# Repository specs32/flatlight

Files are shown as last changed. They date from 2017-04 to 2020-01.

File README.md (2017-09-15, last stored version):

# flatlight

__What is Flatlight?__

A (relatively) powerful light, that nicely fits into your pockets because it's flat like a phone ;)

This Project is intended for educational and private use. (Probably to show how not to do a few things^^)

I designed the "Flatlight" myself, searching for circuits online, creating the schematics and layout with KiCAD.
I  built a few prototypes from bare copper PCB to the finished device, including printing the transparencys, exposing, developing, etching, cleaning, filing, placing the components and toasting the board on my old camping gas stove.

And as you can see im not much of a programmer ...

I got a lot of positive feedback from everyone, so I thought its time to share ! :)

__Building the Flatlight__

You should find everything you need in the KiCAD Folder to get started Hardwarewise.

__Code for the Flatlight__

It started out as a C++ Project in Eclipse, but i found that pretty difficult to set up and handle, so i switched to arduino.
The Arduino Programm is for the Flatlight . 

<B>The Software is Licensed under the GNU Public License 3.0, please include that in your Code</B>

<B> The Hardware is Licensed under CC-BY-SA 4.0 please include this on your Silkscreen or Top/Bottom Copper Layer</B>

Both Licenses can be found in the docs folder

Thanks to everyone who supported me  !!!

HAVE FUN !!!

-Nico

PS: Thanks and credits to cpldcpu for the nice tiny library which i forked here to adapt it to sk6812 RGBW LEDs!

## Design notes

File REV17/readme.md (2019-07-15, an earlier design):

___REV17 changes___

LEDSIDE
- added LED Driver dio5661
- removed temp ntc
- routed pwm through 2 pin header (standoffs and screws only carry VCC and GND now)

ESIDE
- removed NTC network
- added cap ref -> GND
- routed pwm though 2 pin header
- added OLED (0.91" 128x32 ssd1306)
- added IMU  (LSM6D3)
- changed pixels to apa102-2020 chips
- fliped position of pixels and switches
- changed softlatch mosfet to dmc1030ubqf-7 (some tweaking required here for sure)
- changed µC to atmega328-p with qfn-32 footprint
- changed lithium charge management to dio5158

TODO
- create BOM
- correct pin orientation for 2 pin header (pwm signal) on ledside !!!!

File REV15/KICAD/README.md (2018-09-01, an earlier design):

/*

Flatlight Rev 15

    --- KiCad Files

*/

NOTE :

KiCAD is updated to Version 5.x

It should be possible to open the pcbnew files with a fresh KiCad install, 
just add the libs and footprints in the KiCad settings and youre good to go !

The Project Files are in the PROJECT folder ;)

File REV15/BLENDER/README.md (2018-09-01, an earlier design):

/*

    Flatlight Rev 15
    
    --- Blender Files

*/

NOTE: 

Frame and Buttons are not finalized to Dimension, that Stuff is just here to get the Idea ;)

I use Mattercontrol to setup the Printer and export GCode ...

https://github.com/MatterHackers/MatterControl

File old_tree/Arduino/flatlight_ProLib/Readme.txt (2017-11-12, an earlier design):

The Library can be zipped and imported in Arduino(has to be greater version than 1.0.0) or can be directly copied in the
\Documents\Arduino\libraries\ProLib
directory to update the library you have to delete the old one manually and copy the new files in said directory.

The Library is still WIP and with the given .ino you can controll the LED Matrix.
Press the Moon Button to turn it on/off. Double press it to change the pattern. Hold it for Battery status.

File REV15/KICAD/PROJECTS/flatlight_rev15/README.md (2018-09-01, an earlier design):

/*

Flatlight Rev 15

 --- KiCad - Files

*/

NOTE : 

The gerber_rev15 folder contains updated PCB_NEW designs for kicad 
that are _not_ applied to the single PCB versions in the eside / ledside folders.

TODO : 

- need to update files single PCB files

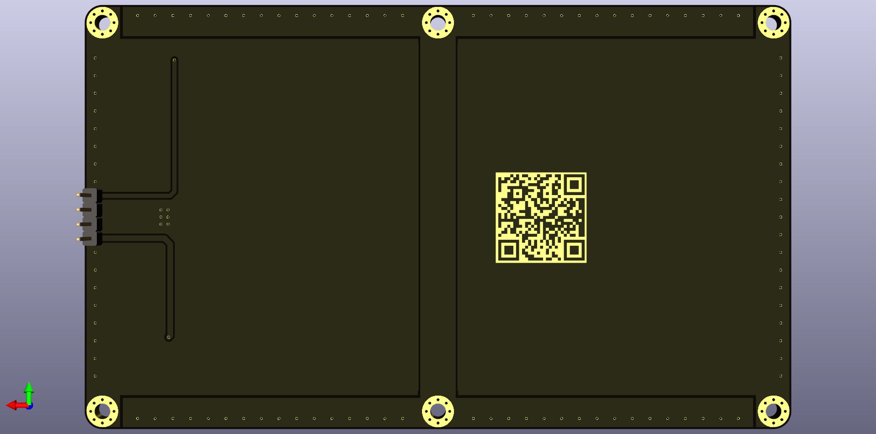
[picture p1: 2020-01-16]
REV18/KiCAD/Project/flatlight_rev18/ledside_rev18A/ledside_rev18A_back.png

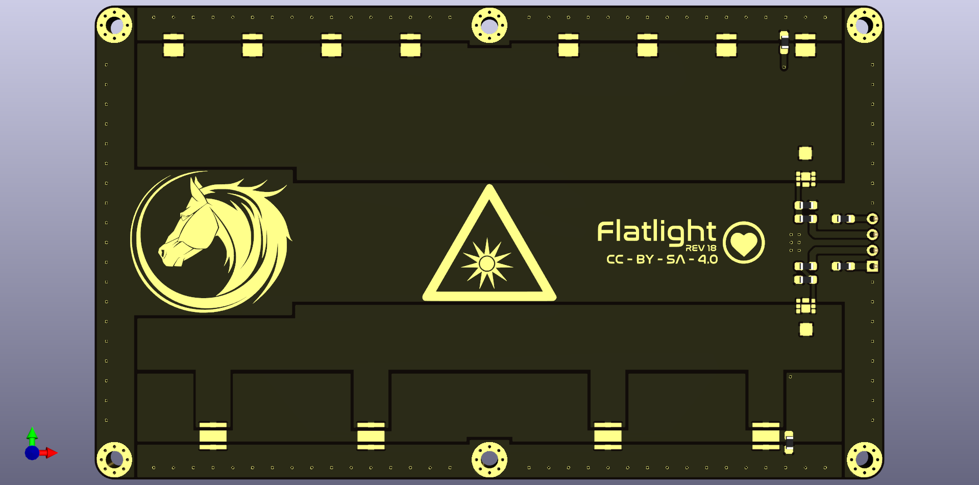
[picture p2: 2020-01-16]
REV18/KiCAD/Project/flatlight_rev18/ledside_rev18A/ledside_rev18A.png

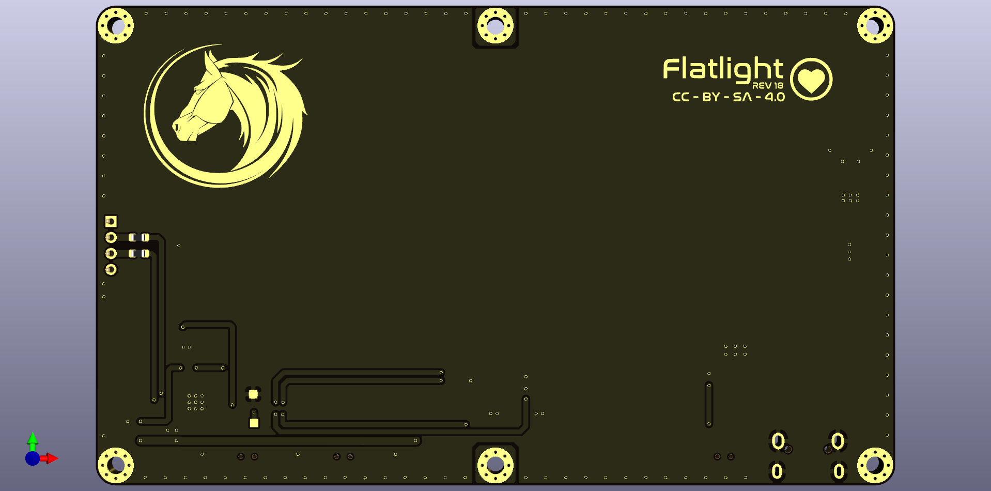
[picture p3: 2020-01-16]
REV18/KiCAD/Project/flatlight_rev18/eside_rev18A/eside_rev18.png

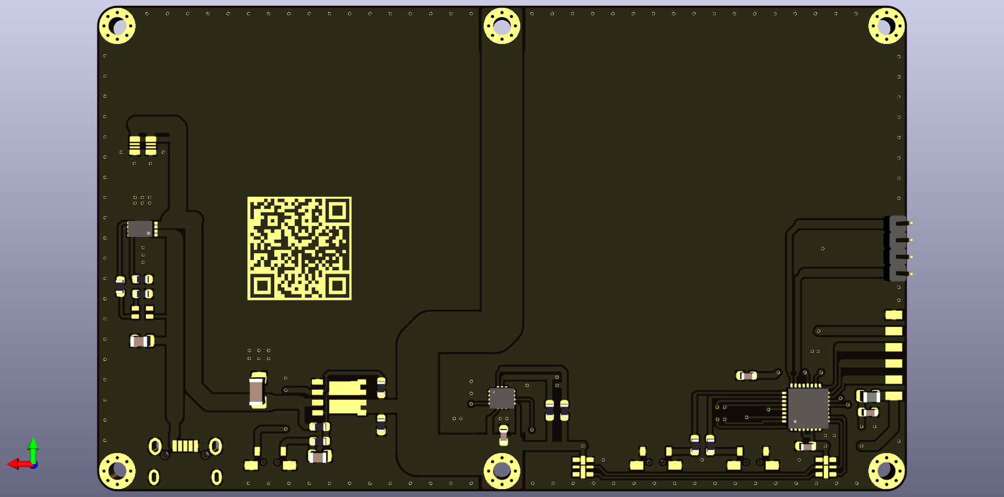
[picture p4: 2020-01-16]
REV18/KiCAD/Project/flatlight_rev18/eside_rev18A/eside_rev18_back.png

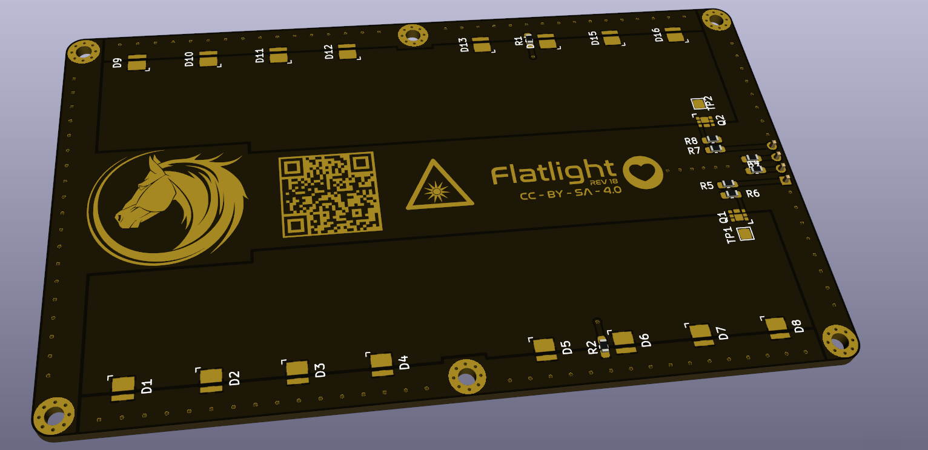
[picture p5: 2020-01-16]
REV18/Ledside_REV18A.png

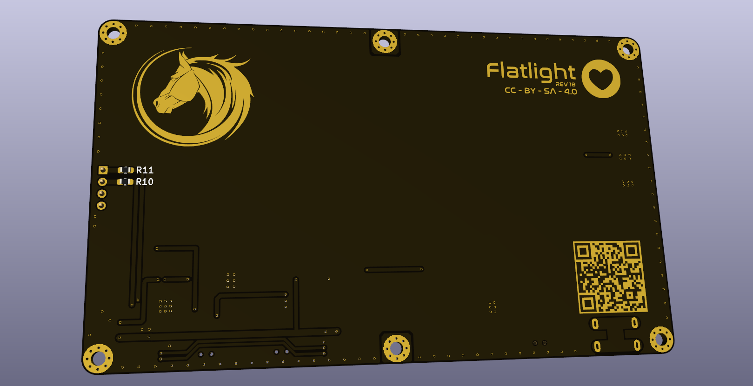
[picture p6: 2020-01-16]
REV18/ESide_REV18A.png

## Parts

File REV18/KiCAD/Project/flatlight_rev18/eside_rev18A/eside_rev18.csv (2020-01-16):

Id | Designator | Package | Quantity | Designation | Supplier and ref
1 | logo4 | logo_heart3 | 1 | logo-heart2
2 | logo1 | logo_flatlight | 1 | logo-flatlight
3 | R7,R6,R9,R8,R13,R12,R4 | R_0603_1608Metric | 7 | 1kΩ
4 | R10,R11,R3,R2 | R_0603_1608Metric | 4 | 10kΩ
5 | TP2,TP1 | TESTPOINT_0.6mm | 2 | TestPoint
6 | J1 | USB_Micro-B_Wuerth_629105150521 | 1 | USB_B_Micro
7 | L1 | L_0805_2012Metric | 1 | 10µH
8 | C5,C7,C4,C6 | C_0603_1608Metric | 4 | 100nF
9 | U2 | Bosch_LGA-14_3x2.5mm_P0.5mm | 1 | LSM6DS3
10 | J3 | PinHeader_1x04_P2.00mm_Vertical | 1 | Conn_01x04
11 | logo5 | logo_flatlight_git_silk | 1 | logo-flatlight-git
12 | logo3 | logo_horse | 1 | logo-horse
13 | logo6 | logo_REV18 | 1 | logo-rev18
14 | C2 | C_1206_3216Metric_Pad1.42x1.75mm_HandSolder | 1 | 10µF
15 | U3 | QFN-32-1EP_5x5mm_P0.5mm_EP3.1x3.1mm | 1 | ATmega328-MU
16 | D3,D2 | LED-APA102-2020 | 2 | APA102-2020
17 | SW3 | white_nano_smd_switch | 1 | BTN_DIG2
18 | SW2 | white_nano_smd_switch | 1 | BTN_DIG1
19 | SW1 | white_nano_smd_switch | 1 | BTN_PWR
20 | R5 | R_0603_1608Metric | 1 | 100kΩ
21 | R1 | R_0603_1608Metric | 1 | 2kΩ
22 | J2 | Conn_01x06_SMD_2mm | 1 | Conn_PROG
23 | H6,H5,H4,H3,H2,H1 | MountingHole_2.2mm_M2_Pad_Via | 6 | MountingHole_Pad
24 | C3 | C_0805_2012Metric | 1 | 1µF
25 | C1 | C_0805_2012Metric | 1 | 10µF
26 | logo2 | cc-by-sa | 1 | logo-cc-by-sa
27 | BT1 | lipo_samsung_BG930ABE | 1 | lipo_sams_BG930ABE
28 | D1 | 0606_ARGB_LED | 1 | LED_ARGB
29 | Q1 | PowerPAK_SO-8_Dual | 1 | DMC1016UPD
30 | U1 | DFN-8-1EP_3x2mm_P0.5mm_EP1.75x1.45mm | 1 | MCP73831-2x3DFN8

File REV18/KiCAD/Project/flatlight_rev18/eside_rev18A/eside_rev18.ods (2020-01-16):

Id | Designator | Package | Quantity | Designation | price per piece | row sum
1 | logo4 | logo_heart3 | 1 | logo-heart2 | 0.0000 EUR | 0.0000 €
2 | logo1 | logo_flatlight | 1 | logo-flatlight | 0.0000 EUR | 0.0000 €
3 | R7,R6,R9,R8,R13,R12,R4 | R_0603_1608Metric | 7 | 1kΩ | 0.0050 EUR | 0.0350 €
4 | R10,R11,R3,R2 | R_0603_1608Metric | 4 | 10kΩ | 0.0050 EUR | 0.0200 €
5 | TP2,TP1 | TESTPOINT_0.6mm | 2 | TestPoint | 0.0000 EUR | 0.0000 €
6 | J1 | USB_Micro-B_Wuerth_629105150521 | 1 | USB_B_Micro | 0.2000 EUR | 0.2000 €
7 | L1 | L_0805_2012Metric | 1 | 10µH | 0.1210 EUR | 0.1210 €
8 | C5,C7,C4,C6 | C_0603_1608Metric | 4 | 100nF | 0.0200 EUR | 0.0800 €
9 | U2 | Bosch_LGA-14_3x2.5mm_P0.5mm | 1 | LSM6DS3 | 2.6200 EUR | 2.6200 €
10 | J3 | PinHeader_1x04_P2.00mm_Vertical | 1 | Conn_01x04 | 0.1000 EUR | 0.1000 €
11 | logo5 | logo_flatlight_git_silk | 1 | logo-flatlight-git | 0.0000 EUR | 0.0000 €
12 | logo3 | logo_horse | 1 | logo-horse | 0.0000 EUR | 0.0000 €
13 | logo6 | logo_REV18 | 1 | logo-rev18 | 0.0000 EUR | 0.0000 €
14 | C2 | C_1206_3216Metric_Pad1.42x1.75mm_HandSolder | 1 | 10µF | 0.3300 EUR | 0.3300 €
15 | U3 | QFN-32-1EP_5x5mm_P0.5mm_EP3.1x3.1mm | 1 | ATmega328-MU | 2.3800 EUR | 2.3800 €
16 | D3,D2 | LED-APA102-2020 | 2 | APA102-2020 | 0.5000 EUR | 1.0000 €
17 | SW3 | white_nano_smd_switch | 1 | BTN_DIG2 | 0.1000 EUR | 0.1000 €
18 | SW2 | white_nano_smd_switch | 1 | BTN_DIG1 | 0.1000 EUR | 0.1000 €
19 | SW1 | white_nano_smd_switch | 1 | BTN_PWR | 0.1000 EUR | 0.1000 €
20 | R5 | R_0603_1608Metric | 1 | 100kΩ | 0.0050 EUR | 0.0050 €
21 | R1 | R_0603_1608Metric | 1 | 2kΩ | 0.0050 EUR | 0.0050 €
22 | J2 | Conn_01x06_SMD_2mm | 1 | Conn_PROG | 0.0000 EUR | 0.0000 €
23 | H6,H5,H4,H3,H2,H1 | MountingHole_2.2mm_M2_Pad_Via | 6 | MountingHole_Pad | 0.0000 EUR | 0.0000 €
24 | C3 | C_0805_2012Metric | 1 | 1µF | 0.0230 EUR | 0.0230 €
25 | C1 | C_0805_2012Metric | 1 | 10µF | 0.1170 EUR | 0.1170 €
26 | logo2 | cc-by-sa | 1 | logo-cc-by-sa | 0.0000 EUR | 0.0000 €
27 | BT1 | lipo_samsung_BG930ABE | 1 | lipo_sams_BG930ABE | 16.9900 EUR | 16.9900 €
28 | D1 | 0606_ARGB_LED | 1 | LED_ARGB | 0.1000 EUR | 0.1000 €
29 | Q1 | PowerPAK_SO-8_Dual | 1 | DMC1016UPD | 0.5580 EUR | 0.5580 €
30 | U1 | DFN-8-1EP_3x2mm_P0.5mm_EP1.75x1.45mm | 1 | MCP73831-2x3DFN8 | 0.5310 EUR | 0.5310 €
31 | D4,D3,D2,D1 | LED_Cree-XP-G | 4 | LED_PAD | 0.6160 EUR | 2.4640 €
32 | R3,R4 | R_0603_1608Metric_Pad1.05x0.95mm_HandSolder | 2 | NTC 10 kΩ | 0.1760 EUR | 0.3520 €
33 | R1,R2 | R_0603_1608Metric_Pad1.05x0.95mm_HandSolder | 2 | 10 kΩ | 0.0050 EUR | 0.0100 €
34 | logo7 | logo_flatlight_git_silk | 1 | logo_flatlight_git | 0.0000 EUR | 0.0000 €
35 | logo2 | logo_horse | 1 | logo_horse | 0.0000 EUR | 0.0000 €
36 | R6,R8 | R_0603_1608Metric_Pad1.05x0.95mm_HandSolder | 2 | 1MΩ | 0.0050 EUR | 0.0100 €
37 | TP1,TP2 | TestPoint_Pad_1.5x1.5mm | 2 | TestPoint | 0.0000 EUR | 0.0000 €
38 | R5,R7 | R_0603_1608Metric_Pad1.05x0.95mm_HandSolder | 2 | 1kΩ | 0.0050 EUR | 0.0100 €
39 | Q1,Q2 | U-DFN2020-6 (Type F) | 2 | DMN2022-UFDF7 | 0.2700 EUR | 0.5400 €
40 | D16,D15,D14,D13,D12,D11,D10,D9 | LED_Cree-J-Series | 8 | LED | 0.0820 EUR | 0.6560 €
41 | logo6 | logo_REV18 | 1 | logo_REV18 | 0.0000 EUR | 0.0000 €
42 | logo3 | cc-by-sa | 1 | logo-cc-by-sa | 0.0000 EUR | 0.0000 €
43 | J1 | PinHeader_1x04_P2.00mm_Vertical | 1 | Conn_01x04 | 0.1000 EUR | 0.1000 €
44 | H6,H5,H4,H3,H2,H1 | MountingHole_2.2mm_M2_Pad_Via | 6 | MountingHole_Pad | 0.0000 EUR | 0.0000 €
45 | logo1 | logo_heart3 | 1 | logo_heart | 0.0000 EUR | 0.0000 €
46 | logo5 | logo_flatlight | 1 | logo_flatlight | 0.0000 EUR | 0.0000 €
47 | logo4 | logo_lightwarn_15mm | 1 | logo_LIGHTWARN | 0.0000 EUR | 0.0000 €
48 | verbrauch | zinn, flux, draht, etc. | 1 |  | 3.0000 EUR | 3.0000 €
49 | messing einsätze | rahmen besfestigung | 6 |  | 0.0700 EUR | 0.4200 €
50 | schrauben | rahmen besfestigung | 6 |  | 0.0100 EUR | 0.0600 €
51 |  |  |  |  |  | 33.1370 €

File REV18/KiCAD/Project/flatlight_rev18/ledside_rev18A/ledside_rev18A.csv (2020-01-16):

Id | Designator | Package | Quantity | Designation | Supplier and ref
1 | D4,D3,D2,D1 | LED_Cree-XP-G | 4 | LED_PAD
2 | R3,R4 | R_0603_1608Metric_Pad1.05x0.95mm_HandSolder | 2 | NTC 10 kΩ
3 | R1,R2 | R_0603_1608Metric_Pad1.05x0.95mm_HandSolder | 2 | 10 kΩ
4 | logo7 | logo_flatlight_git_silk | 1 | logo_flatlight_git
5 | logo2 | logo_horse | 1 | logo_horse
6 | R6,R8 | R_0603_1608Metric_Pad1.05x0.95mm_HandSolder | 2 | 1MΩ
7 | TP1,TP2 | TestPoint_Pad_1.5x1.5mm | 2 | TestPoint
8 | R5,R7 | R_0603_1608Metric_Pad1.05x0.95mm_HandSolder | 2 | 1kΩ
9 | Q1,Q2 | U-DFN2020-6 (Type F) | 2 | DMN2022-UFDF7
10 | D16,D15,D14,D13,D12,D11,D10,D9 | LED_Cree-J-Series | 8 | LED
11 | logo6 | logo_REV18 | 1 | logo_REV18
12 | logo3 | cc-by-sa | 1 | logo-cc-by-sa
13 | J1 | PinHeader_1x04_P2.00mm_Vertical | 1 | Conn_01x04
14 | H6,H5,H4,H3,H2,H1 | MountingHole_2.2mm_M2_Pad_Via | 6 | MountingHole_Pad
15 | logo1 | logo_heart3 | 1 | logo_heart
16 | logo5 | logo_flatlight | 1 | logo_flatlight
17 | logo4 | logo_lightwarn_15mm | 1 | logo_LIGHTWARN

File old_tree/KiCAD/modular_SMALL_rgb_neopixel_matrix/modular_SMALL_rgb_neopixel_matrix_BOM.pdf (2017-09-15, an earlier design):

modular_SMALL_rgb_neopixel_matrix

Kicad Rev | Eeschema 4.0.6
Date Issue | Sat 09 Sep 2017 10:44:32 GMT
Title | Modular Flatlight
Company | Nicolas Rosenthal
Revision | 8
Date Issue | 2017-07-24
Comment | CC-BY-SA-4.0
Comment | Flatlight
Reference | Value | Library | Library Ref | Price
Q1 | IRF7319 | transistors | IRF7343PBF | 0.411760 €
U1 | TP4056 | nicos-parts | TP4056 | 0.360000 €
J1 | USB_Micro_Jack | conn | USB_B | 0.520000 €
R1 | 1.2KΩ | device | R | 0.005880 €
R2 | 1KΩ | device | R | 0.005880 €
R3 | 1KΩ | device | R | 0.058800 €
D1 | RED | device | LED | 0.067230 €
D2 | GREEN | device | LED | 0.084030 €
C1 | 10µF | device | C | 0.050420 €
C2 | 10µF | device | C | 0.050420 €
R6 | 100KΩ | device | R | 0.005880 €
R5 | 10KΩ | device | R | 0.005880 €
R4 | 100KΩ | device | R | 0.005880 €
C3 | 1µF | device | C | 0.033610 €
R7 | 10KΩ | device | R | 0.005880 €
SW1 | SW_PWR | switches | SW_Push | 0.040000 €
C7 | 100nF_decoupling | device | C | 0.033610 €
D9 | TMPWARN_RED | device | LED | 0.067230 €
R23 | 237Ω | device | R | 0.005880 €
SW2 | SW_MODE | switches | SW_Push | 0.040000 €
R22 | 10KΩ | device | R | 0.005880 €
D8 | PWRLED_GRN | device | LED | 0.180000 €
R21 | 237Ω | device | R | 0.005880 €
R17 | 15KΩ | device | R | 0.005880 €
BAT1 | LIPO_W_NTC | nicos-parts | LIPO_W_NTC | 3.850000 €
D7 | CHRG_IND_RED | device | LED | 0.067230 €
D6 | CHRG_IND_ORANGE | device | LED | 0.084030 €
D5 | CHRG_IND_YELLOW | device | LED | 0.050420 €
D4 | CHRG_IND_GREEN | device | LED | 0.084030 €
D3 | CHRG_IND_BRTGREEN | device | LED | 0.134450 €
RN1 | R_Pack_220Ω | device | R_Pack04 | 0.016800 €
R8 | 237Ω | device | R | 0.005880 €
J12 | CONN_VCC_FEMALE | conn | CONN_01X03 | 0.100000 €
J10 | CONN_PWM_1_FEMALE | conn | CONN_01X03 | 0.100000 €
J6 | CONN_VCC_FEMALE | conn | CONN_01X03 | 0.100000 €
J4 | CONN_PWM_2_FEMALE | conn | CONN_01X03 | 0.100000 €
U2 | ATMEGA16-16AU | atmel | ATMEGA16-16AU | 1.630000 €
C6 | 100nF | device | C | 0.033610 €

L1 | 100µH | device | L | 0.160000 €
SW3 | SW_MODE2 | switches | SW_Push | 0.040000 €
R9 | 10KΩ | device | R | 0.005880 €
J2 | CONN_01X08 | conn | CONN_01X08 | 0.200000 €
Q2 | IRLML6244 | device | Q_NMOS_GSD | 0.190240 €
R10 | 1KΩ | device | R | 0.005880 €
C4 | 10µF TANT | device | CP | 0.100800 €
U26 | SK6812 | SK6812_3535 LED | 0.100000 €
C27 | 100nF | device | C | 0.033610 €
U27 | SK6812 | SK6812_3535 LED | 0.100000 €
C28 | 100nF | device | C | 0.033610 €
U28 | SK6812 | SK6812_3535 LED | 0.100000 €
C29 | 100nF | device | C | 0.033610 €
U29 | SK6812 | SK6812_3535 LED | 0.100000 €
C30 | 100nF | device | C | 0.033610 €
U30 | SK6812 | SK6812_3535 LED | 0.100000 €
C31 | 100nF | device | C | 0.033610 €
U31 | SK6812 | SK6812_3535 LED | 0.100000 €
C32 | 100nF | device | C | 0.033610 €
U32 | SK6812 | SK6812_3535 LED | 0.100000 €
C33 | 100nF | device | C | 0.033610 €
U33 | SK6812 | SK6812_3535 LED | 0.100000 €
C34 | 100nF | device | C | 0.033610 €
U34 | SK6812 | SK6812_3535 LED | 0.100000 €
C35 | 100nF | device | C | 0.033610 €
U35 | SK6812 | SK6812_3535 LED | 0.100000 €
C36 | 100nF | device | C | 0.033610 €
U36 | SK6812 | SK6812_3535 LED | 0.100000 €
C37 | 100nF | device | C | 0.033610 €
U37 | SK6812 | SK6812_3535 LED | 0.100000 €
C38 | 100nF | device | C | 0.033610 €
U38 | SK6812 | SK6812_3535 LED | 0.100000 €
C39 | 100nF | device | C | 0.033610 €
U39 | SK6812 | SK6812_3535 LED | 0.100000 €
C40 | 100nF | device | C | 0.033610 €
U40 | SK6812 | SK6812_3535 LED | 0.100000 €
C41 | 100nF | device | C | 0.033610 €
U41 | SK6812 | SK6812_3535 LED | 0.100000 €
C42 | 100nF | device | C | 0.033610 €
U42 | SK6812 | SK6812_3535 LED | 0.100000 €
C43 | 100nF | device | C | 0.033610 €
U43 | SK6812 | SK6812_3535 LED | 0.100000 €
C44 | 100nF | device | C | 0.033610 €
U44 | SK6812 | SK6812_3535 LED | 0.100000 €
C45 | 100nF | device | C | 0.033610 €
U45 | SK6812 | SK6812_3535 LED | 0.100000 €
C46 | 100nF | device | C | 0.033610 €
U46 | SK6812 | SK6812_3535 LED | 0.100000 €
C47 | 100nF | device | C | 0.033610 €

U47 | SK6812 | SK6812_3535 LED | 0.100000 €
C48 | 100nF | device | C | 0.033610 €
U48 | SK6812 | SK6812_3535 LED | 0.100000 €
J4 | CONN_01X03 | conn | CONN_01X03 | 0.100000 €
J1 | CONN_01X03 | conn | CONN_01X03 | 0.100000 €
J2 | CONN_01X03 | conn | CONN_01X03 | 0.100000 €
J5 | CONN_01X03 | conn | CONN_01X03 | 0.100000 €
J3 | CONN_01X08 | conn | CONN_01X08 | 0.200000 €
MAT | Fotoplatine | | | 2.550000 €
MAT | Ätzmittel | | | 0.500000 €
MAT | Epoxy | | | 0.500000 €
MAT | VIAS | | | 0.500000 €
MAT | Folie,Draht,Klebeband,Zinn,etc | | | 1.000000 €
GESAMT | | | | 17.804580 €

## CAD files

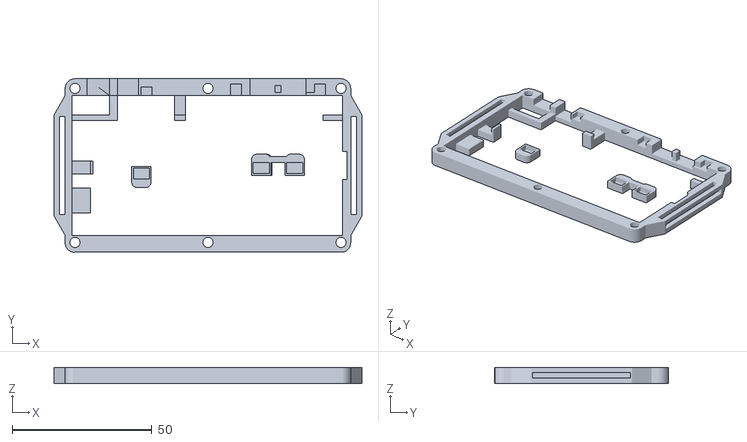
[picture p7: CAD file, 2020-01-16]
REV18/Blender/flatlight_rev18.stl
110.0 x 62.0 x 5.80

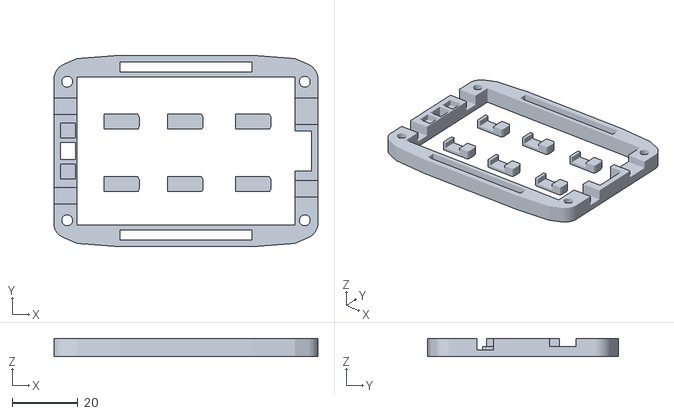
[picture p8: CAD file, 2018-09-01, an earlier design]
REV15/BLENDER/flatlight_rev15/flatlight_rev15_16.stl
80.0 x 58.0 x 5.50

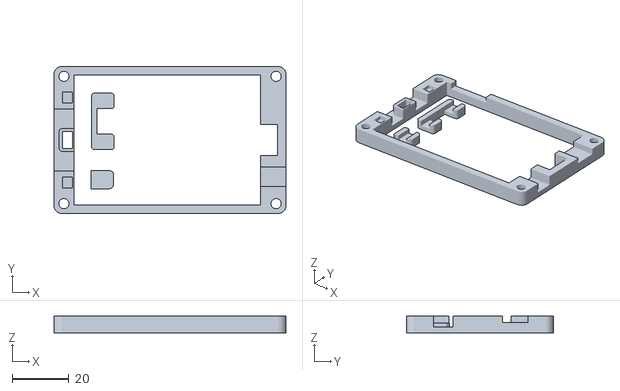
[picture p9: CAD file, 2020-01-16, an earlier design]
REV17/Blender/flatlight_rev17_28.stl
82.0 x 52.0 x 5.90

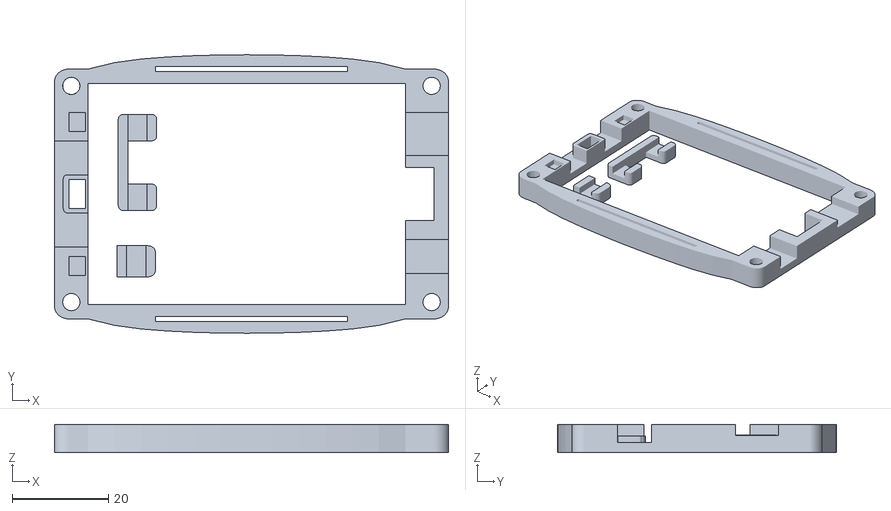
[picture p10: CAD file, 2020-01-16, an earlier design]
REV17/Blender/flatlight_rev17_30.stl
82.0 x 58.0 x 5.90

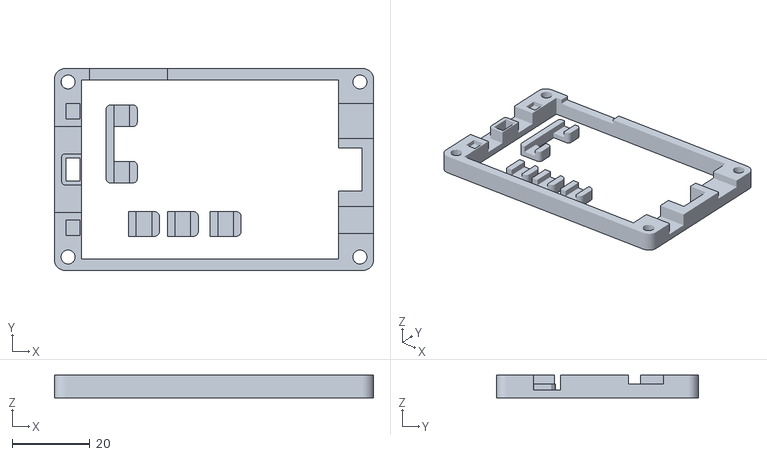
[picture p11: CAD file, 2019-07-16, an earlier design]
REV17/Blender/flatlight_rev17_22.stl
82.0 x 52.0 x 5.80

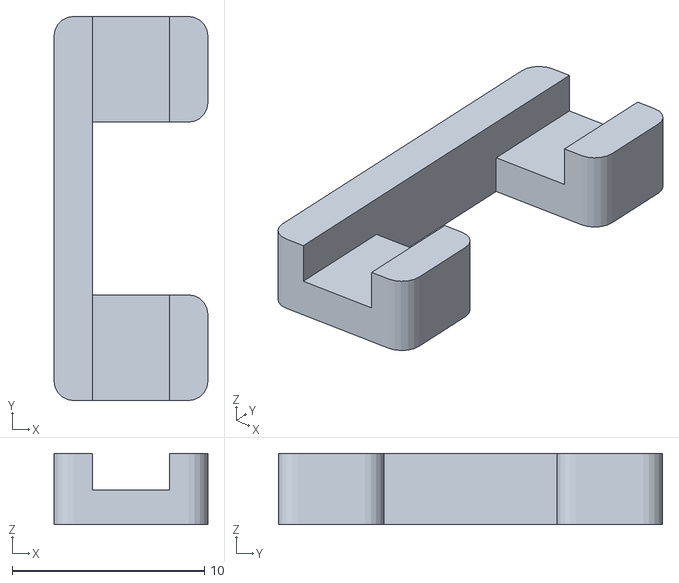
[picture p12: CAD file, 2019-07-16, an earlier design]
REV17/Blender/flatlight_rev17_23-Cube_001.stl
8.01 x 20.0 x 3.70

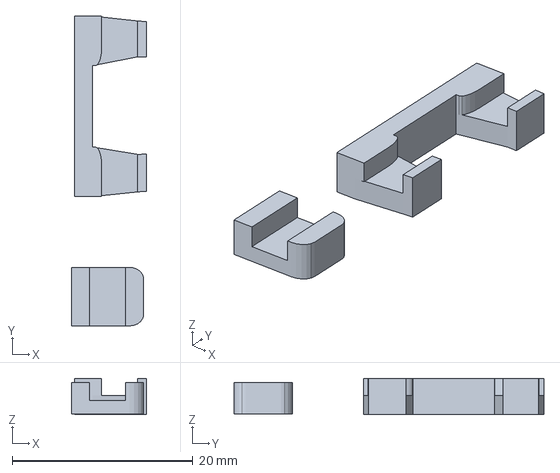
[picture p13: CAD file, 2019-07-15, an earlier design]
REV17/Blender/flatlight_rev17_14 (1).amf
8.31 x 34.3 x 4.00 mm

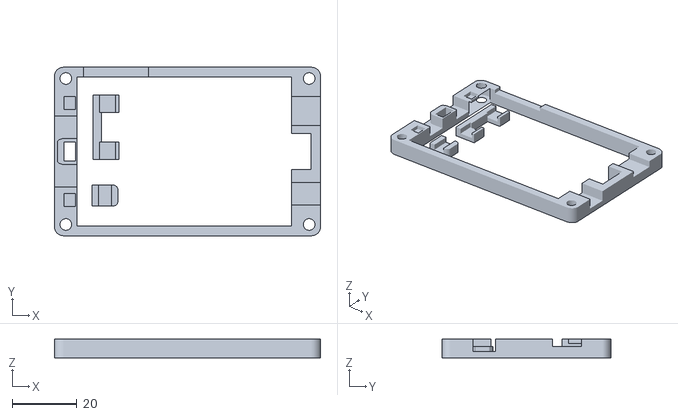
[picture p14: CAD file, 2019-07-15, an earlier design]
REV17/Blender/flatlight_rev17_11.stl
82.0 x 52.0 x 5.80

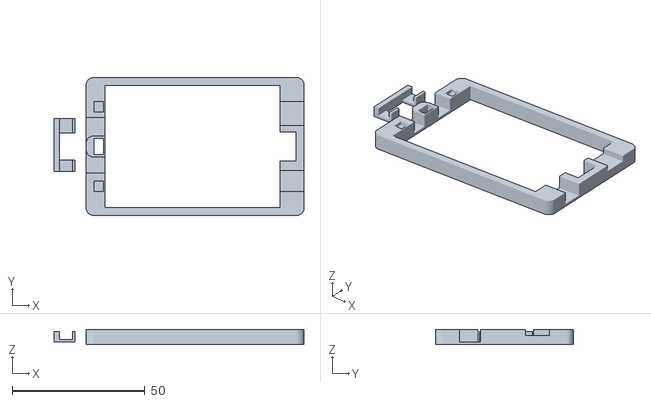
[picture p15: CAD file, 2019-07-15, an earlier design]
REV17/Blender/flatlight_rev17_9.stl
94.1 x 52.0 x 5.80

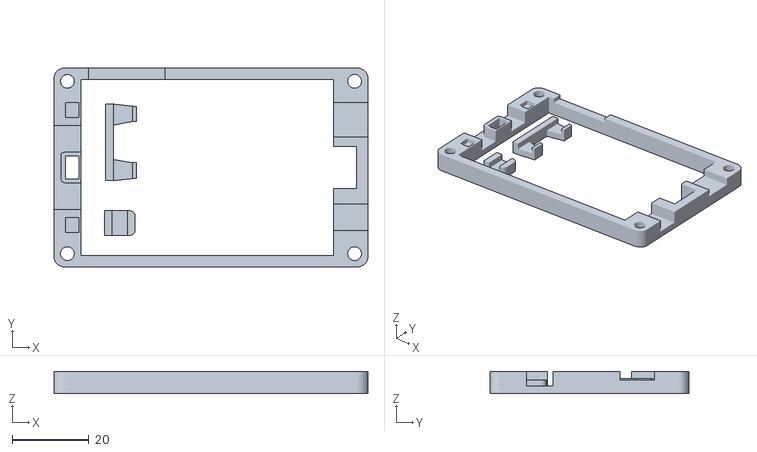
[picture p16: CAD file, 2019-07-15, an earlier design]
REV17/Blender/flatlight_rev17_17.stl
82.0 x 52.0 x 5.80

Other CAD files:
REV17/Blender/flatlight_rev17_test.stl
REV17/Blender/flatlight_rev17_23.stl
REV17/Blender/flatlight_rev17_26.stl
REV17/Blender/flatlight_rev17_27.stl
REV17/Blender/flatlight_rev17_20.stl
REV17/Blender/flatlight_rev17_19.stl
REV17/Blender/flatlight_rev17_14.stl
REV17/Blender/flatlight_rev17_21.stl
REV15/BLENDER/flatlight_rev15/flatlight_rev15_1.blend
REV15/BLENDER/flatlight_rev15/flatlight_rev15_10.blend
REV15/BLENDER/flatlight_rev15/flatlight_rev15_11.blend
REV15/BLENDER/flatlight_rev15/flatlight_rev15_12.blend
REV15/BLENDER/flatlight_rev15/flatlight_rev15_13.blend
REV15/BLENDER/flatlight_rev15/flatlight_rev15_14.blend
REV15/BLENDER/flatlight_rev15/flatlight_rev15_15.blend
REV15/BLENDER/flatlight_rev15/flatlight_rev15_16.blend
REV15/BLENDER/flatlight_rev15/flatlight_rev15_2.blend
REV15/BLENDER/flatlight_rev15/flatlight_rev15_3.blend
REV15/BLENDER/flatlight_rev15/flatlight_rev15_4.blend
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

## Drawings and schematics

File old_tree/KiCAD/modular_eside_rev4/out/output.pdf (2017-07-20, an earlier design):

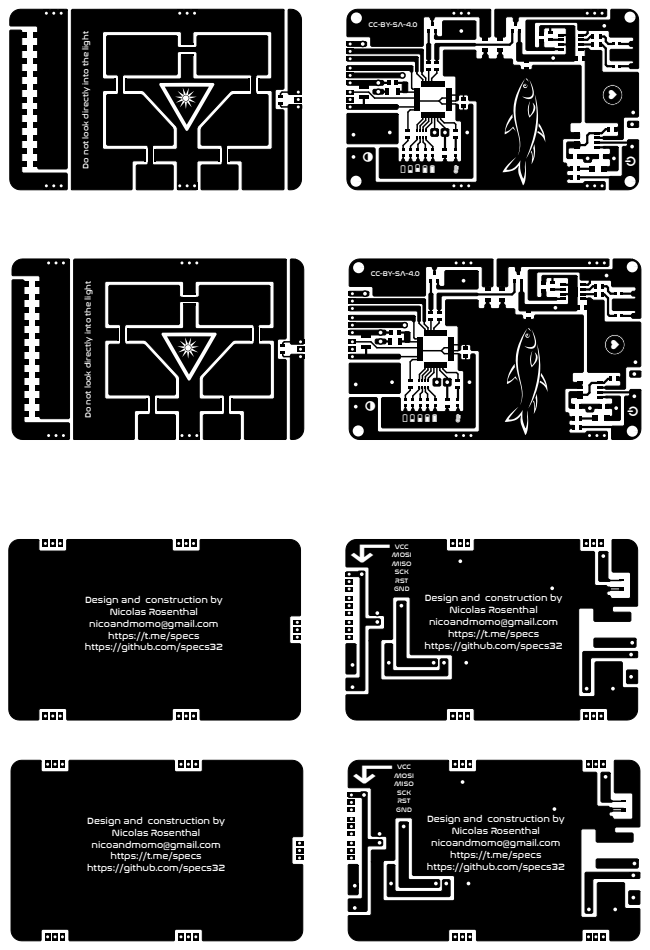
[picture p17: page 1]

Do not look directly into the light

VCC
OSI
ISO
SCK
RST
GND
Design and construction by
Nicolas Rosenthal
nicoandmomo@gmail.com
https://t.me/specs
https://github.com/specs32

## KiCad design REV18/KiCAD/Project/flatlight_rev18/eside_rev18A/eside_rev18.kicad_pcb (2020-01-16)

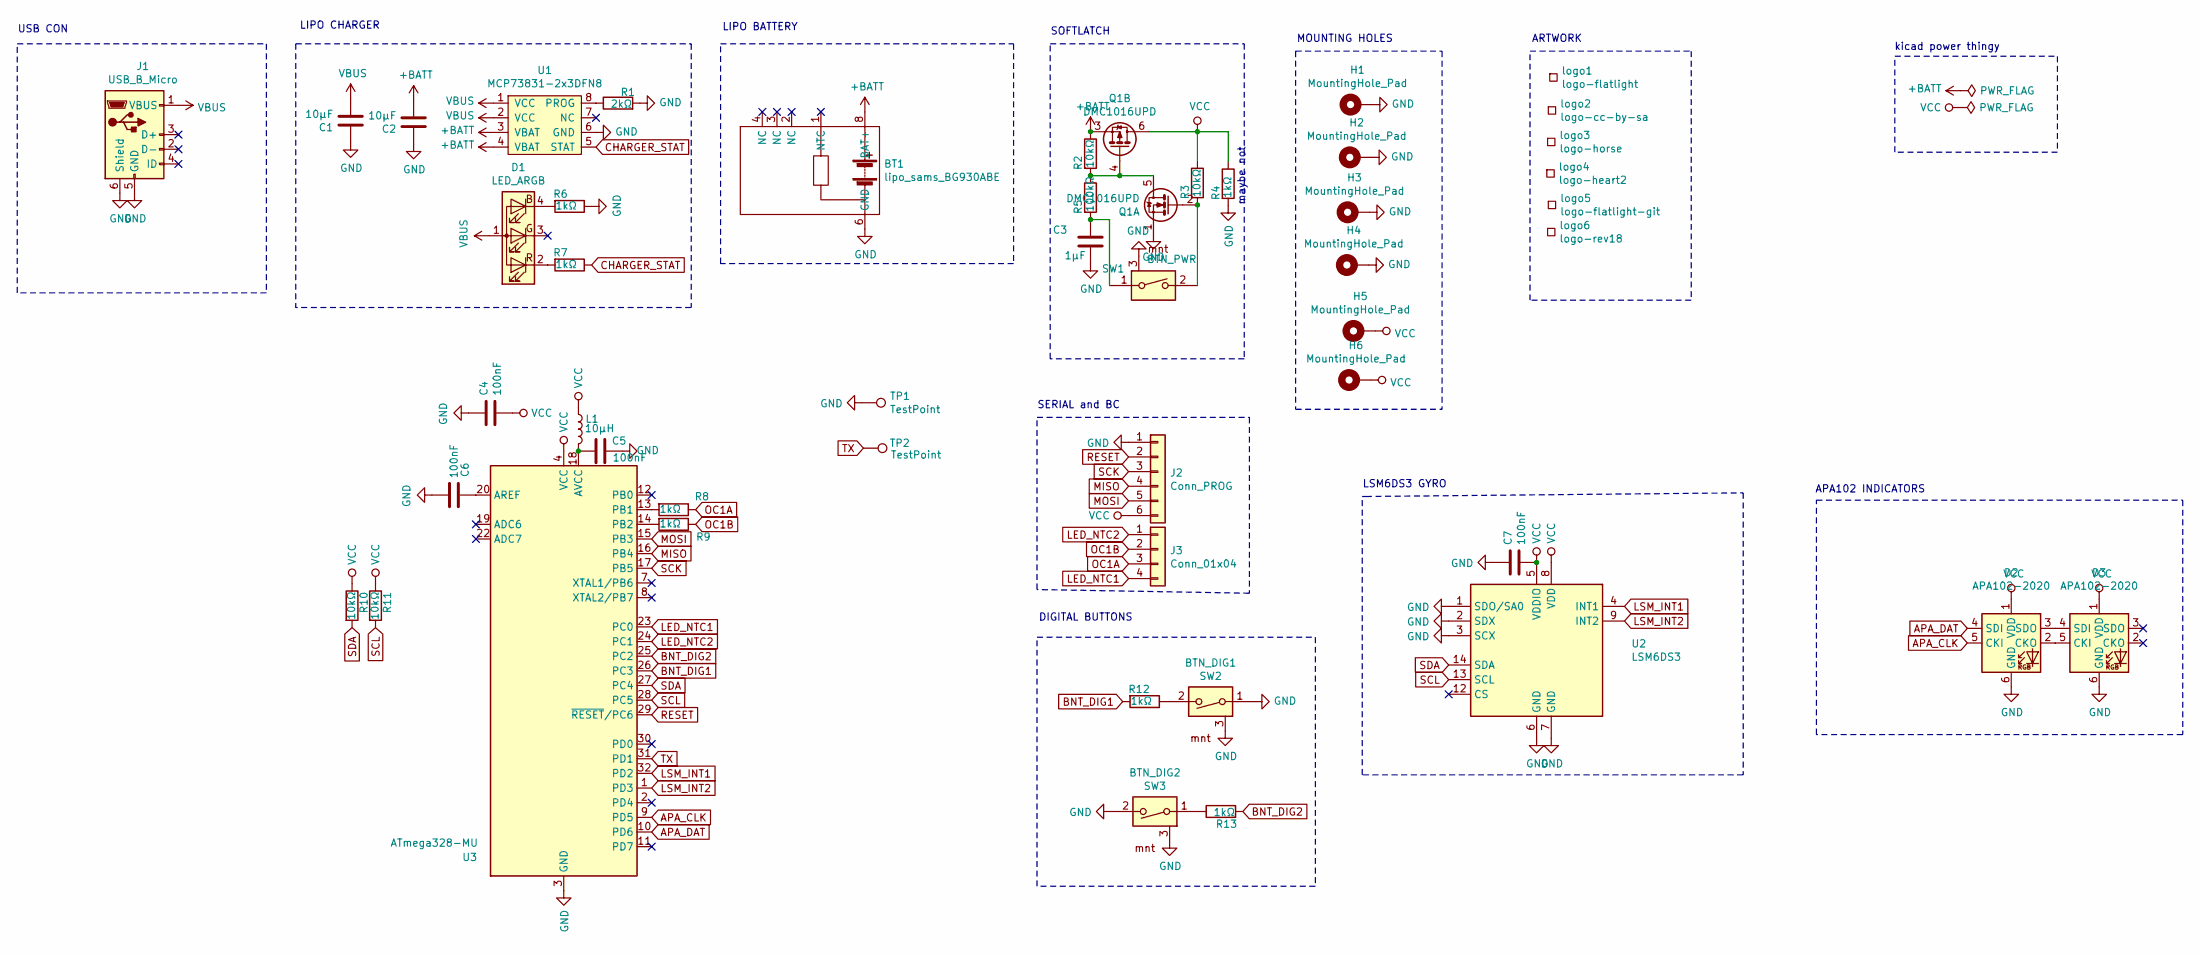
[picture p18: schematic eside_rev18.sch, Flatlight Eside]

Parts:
BT1: lipo_sams_BG930ABE; lipo_samsung_BG930ABE
C1: 10µF; C_0805_2012Metric
C2: 10µF; C_1206_3216Metric_Pad1.42x1.75mm_HandSolder
C3: 1µF; C_0805_2012Metric
C4, C5, C6, C7: 100nF; C_0603_1608Metric
D1: LED_ARGB; 0606_ARGB_LED
D2, D3: APA102-2020; LED-APA102-2020
H1, H2, H3, H4, H5, H6: MountingHole_Pad; MountingHole_2.2mm_M2_Pad_Via
J1: USB_B_Micro; USB_Micro-B_Wuerth_629105150521
J2: Conn_PROG; Conn_01x06_SMD_2mm
J3: Conn_01x04; PinHeader_1x04_P2.00mm_Vertical
L1: 10µH; L_0805_2012Metric
Q1: DMC1016UPD; PowerPAK_SO-8_Dual
R1: 2kΩ; R_0603_1608Metric
R2, R3, R10, R11: 10kΩ; R_0603_1608Metric
R4, R6, R7, R8, R9, R12, R13: 1kΩ; R_0603_1608Metric
R5: 100kΩ; R_0603_1608Metric
SW1: BTN_PWR; white_nano_smd_switch
SW2: BTN_DIG1; white_nano_smd_switch
SW3: BTN_DIG2; white_nano_smd_switch
TP1, TP2: TestPoint; TestPoint_Pad_1.0x1.0mm
U1: MCP73831-2x3DFN8; DFN-8-1EP_3x2mm_P0.5mm_EP1.75x1.45mm
U2: LSM6DS3; Bosch_LGA-14_3x2.5mm_P0.5mm
U3: ATmega328-MU; QFN-32-1EP_5x5mm_P0.5mm_EP3.1x3.1mm
logo1: logo-flatlight; logo_flatlight
logo2: logo-cc-by-sa; cc-by-sa
logo3: logo-horse; logo_horse
logo4: logo-heart2; logo_heart3
logo5: logo-flatlight-git; logo_flatlight_git_silk
logo6: logo-rev18; logo_REV18

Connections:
+BATT: BT1.7 (BAT+), BT1.8 (BAT+), C2.2, Q1.3 (1), R2.1, U1.3 (VBAT), U1.4 (VBAT)
APA_CLK: D2.5 (CKI), U3.9 (PD5)
APA_DAT: D2.4 (SDI), U3.10 (PD6)
BNT_DIG1: R12.2, U3.26 (PC3)
BNT_DIG2: R13.2, U3.25 (PC2)
CHARGER_STAT: R7.1, U1.5 (STAT)
GND: BT1.5 (GND), BT1.6 (GND), C1.1, C2.1, C3.2, C4.1, C5.1, C6.2, C7.1, D2.6 (GND), D3.6 (GND), H1.1, H2.1, H3.1, H4.1, J1.5 (GND), J1.6 (Shield), J2.1, Q1.1 (S), R1.2, R4.2, R6.1, SW1.3, SW2.1, SW2.3, SW3.2, SW3.3, TP1.1, U1.6 (GND), U1.9 (GND), U2.1 (SDO/SA0), U2.2 (SDX), U2.3 (SCX), U2.6 (GND), U2.7 (GND), U3.3 (GND), U3.5 (GND), U3.21 (GND), U3.33 (GND)
LED_NTC1: J3.4, U3.23 (PC0)
LED_NTC2: J3.1, U3.24 (PC1)
LSM_INT1: U2.4 (INT1), U3.32 (PD2)
LSM_INT2: U2.9 (INT2), U3.1 (PD3)
MISO: J2.4, U3.16 (PB4)
MOSI: J2.5, U3.15 (PB3)
unnamed: C3.1, R5.2, SW1.1
unnamed: C5.2, L1.2, U3.18 (AVCC)
unnamed: C6.1, U3.20 (AREF)
unnamed: D1.2 (RK), R7.2
unnamed: D1.4 (BK), R6.2
unnamed: D2.2 (CKO), D3.5 (CKI)
unnamed: D2.3 (SDO), D3.4 (SDI)
unnamed: Q1.2 (G), R3.2, SW1.2
unnamed: Q1.4 (G), Q1.5 (D), R2.2, R5.1
unnamed: R1.1, U1.8 (PROG)
unnamed: R8.2, U3.13 (PB1)
unnamed: R9.2, U3.14 (PB2)
unnamed: R12.1, SW2.2
unnamed: R13.1, SW3.1
OC1A: J3.3, R8.1
OC1B: J3.2, R9.1
RESET: J2.2, U3.29 (~RESET~/PC6)
SCK: J2.3, U3.17 (PB5)
SCL: R11.2, U2.13 (SCL), U3.28 (PC5)
SDA: R10.2, U2.14 (SDA), U3.27 (PC4)
TX: TP2.1, U3.31 (PD1)
VBUS: C1.2, D1.1 (A), J1.1 (VBUS), U1.1 (VCC), U1.2 (VCC)
VCC: C4.2, C7.2, D2.1 (VDD), D3.1 (VDD), H5.1, H6.1, J2.6, L1.1, Q1.6 (D), R3.1, R4.1, R10.1, R11.1, U2.5 (VDDIO), U2.8 (VDD), U3.4 (VCC), U3.6 (VCC)

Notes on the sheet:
APA102 INDICATORS
DIGITAL BUTTONS
MOUNTING HOLES
ARTWORK
LIPO BATTERY
LIPO CHARGER
USB CON
SERIAL and BC
SOFTLATCH
LSM6DS3 GYRO
kicad power thingy
maybe not

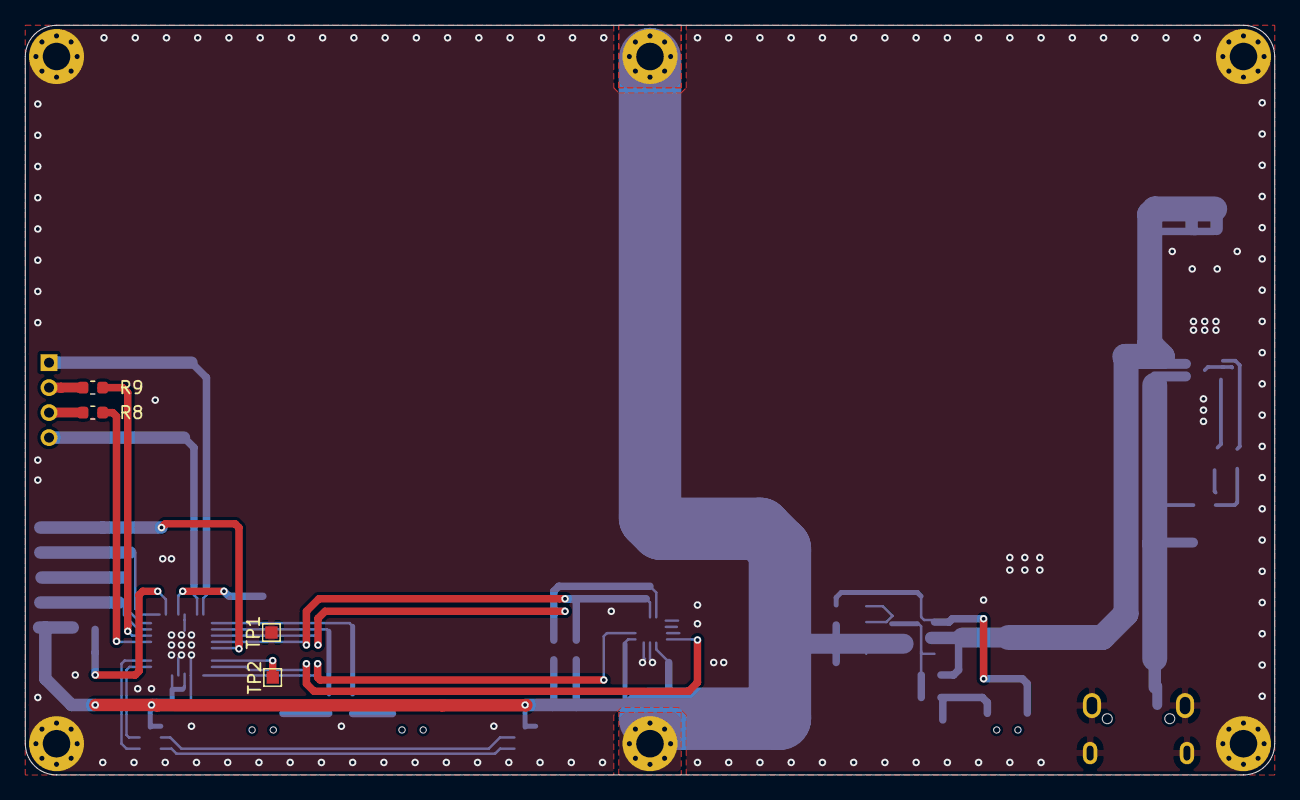
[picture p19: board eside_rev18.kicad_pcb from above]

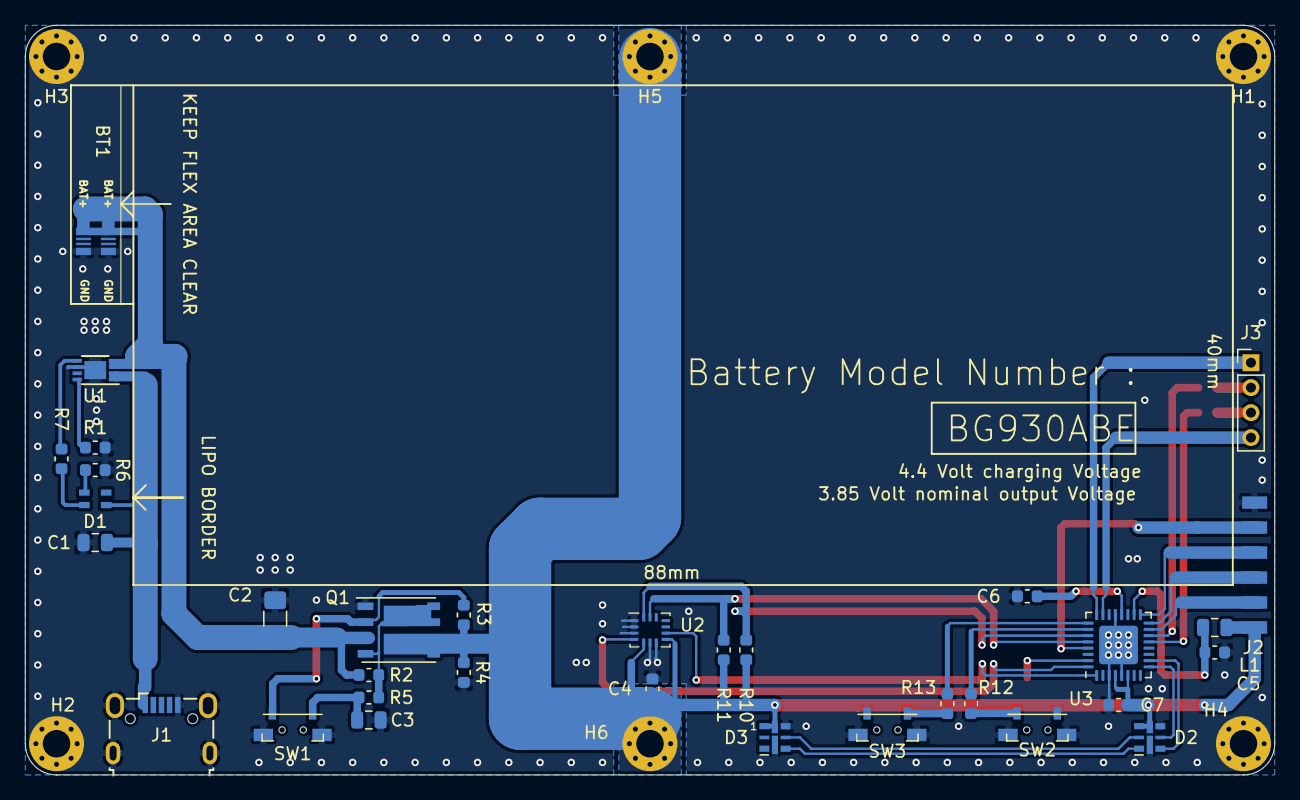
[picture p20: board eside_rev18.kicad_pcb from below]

Board: 2 copper layers, 100.0 x 60.0 mm, 49 parts (40 on the bottom side), 36 nets.

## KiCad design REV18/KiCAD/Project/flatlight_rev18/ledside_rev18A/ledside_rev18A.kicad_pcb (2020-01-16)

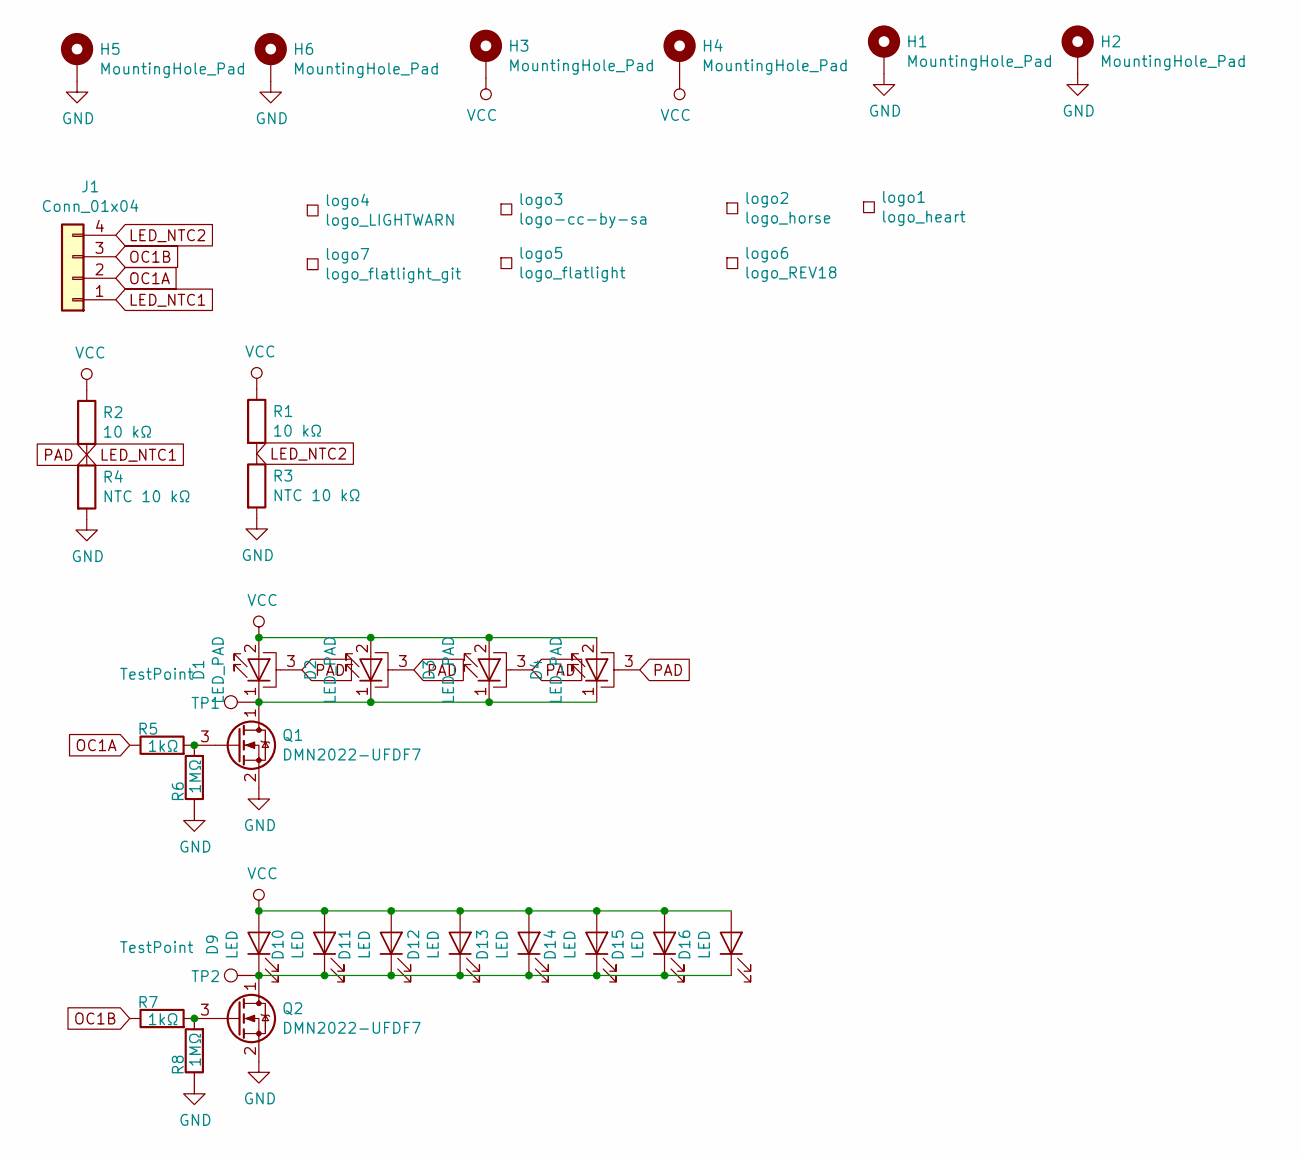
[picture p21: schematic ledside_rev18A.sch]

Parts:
D1, D2, D3, D4: LED_PAD; LED_Cree-XP-G
D9, D10, D11, D12, D13, D14, D15, D16: LED; LED_Cree-J-Series
H1, H2, H3, H4, H5, H6: MountingHole_Pad; MountingHole_2.2mm_M2_Pad_Via
J1: Conn_01x04; PinHeader_1x04_P2.00mm_Vertical
Q1, Q2: DMN2022-UFDF7; U-DFN2020-6 (Type F)
R1, R2: 10 kΩ; R_0603_1608Metric_Pad1.05x0.95mm_HandSolder
R3, R4: NTC 10 kΩ; R_0603_1608Metric_Pad1.05x0.95mm_HandSolder
R5, R7: 1kΩ; R_0603_1608Metric_Pad1.05x0.95mm_HandSolder
R6, R8: 1MΩ; R_0603_1608Metric_Pad1.05x0.95mm_HandSolder
TP1, TP2: TestPoint; TestPoint_Pad_1.5x1.5mm
logo1: logo_heart; logo_heart3
logo2: logo_horse
logo3: logo-cc-by-sa; cc-by-sa
logo4: logo_LIGHTWARN; logo_lightwarn_15mm
logo5: logo_flatlight
logo6: logo_REV18
logo7: logo_flatlight_git; logo_flatlight_git_silk

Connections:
GND: H1.1, H2.1, H5.1, H6.1, Q1.2 (S), Q2.2 (S), R3.2, R4.2, R6.1, R8.1
LED_NTC1: D1.3 (PAD), D2.3 (PAD), D3.3 (PAD), D4.3 (PAD), J1.1, R2.2, R4.1
LED_NTC2: J1.4, R1.2, R3.1
unnamed: D1.1 (K), D2.1 (K), D3.1 (K), D4.1 (K), Q1.1 (D), TP1.1
unnamed: D9.1 (K), D10.1 (K), D11.1 (K), D12.1 (K), D13.1 (K), D14.1 (K), D15.1 (K), D16.1 (K), Q2.1 (D), TP2.1
unnamed: Q1.3 (G), R5.2, R6.2
unnamed: Q2.3 (G), R7.2, R8.2
OC1A: J1.2, R5.1
OC1B: J1.3, R7.1
VCC: D1.2 (A), D2.2 (A), D3.2 (A), D4.2 (A), D9.2 (A), D10.2 (A), D11.2 (A), D12.2 (A), D13.2 (A), D14.2 (A), D15.2 (A), D16.2 (A), H3.1, H4.1, R1.1, R2.1

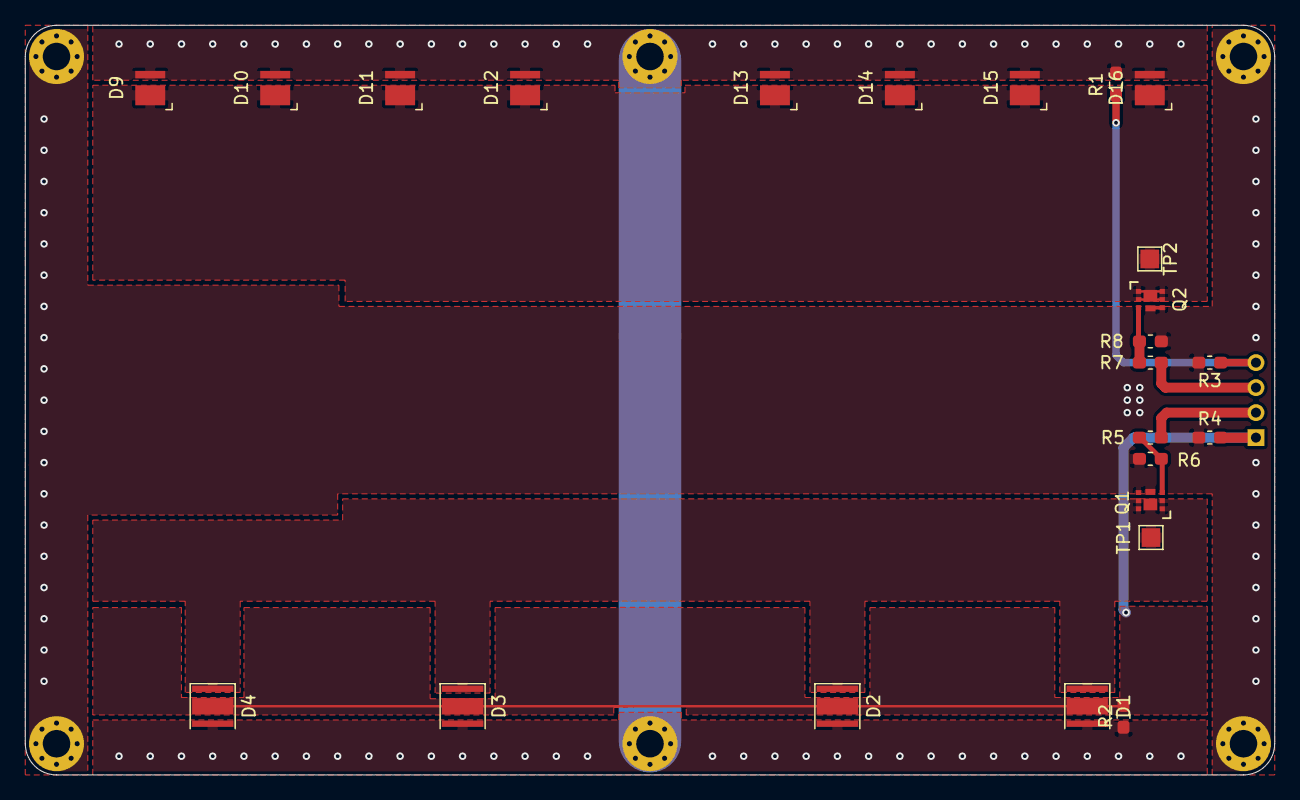
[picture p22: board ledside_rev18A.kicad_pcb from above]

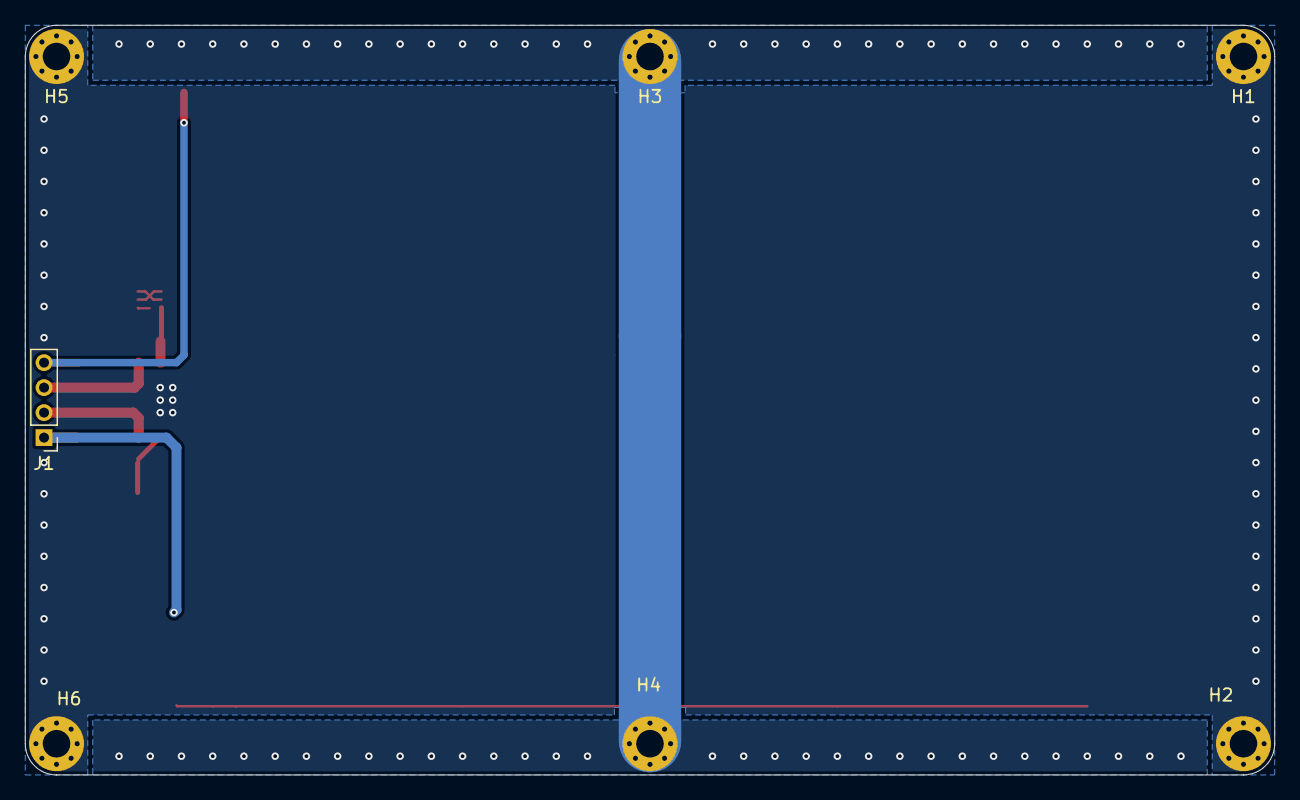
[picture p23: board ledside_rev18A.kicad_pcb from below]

Board: 2 copper layers, 100.0 x 60.0 mm, 38 parts (8 on the bottom side), 10 nets.

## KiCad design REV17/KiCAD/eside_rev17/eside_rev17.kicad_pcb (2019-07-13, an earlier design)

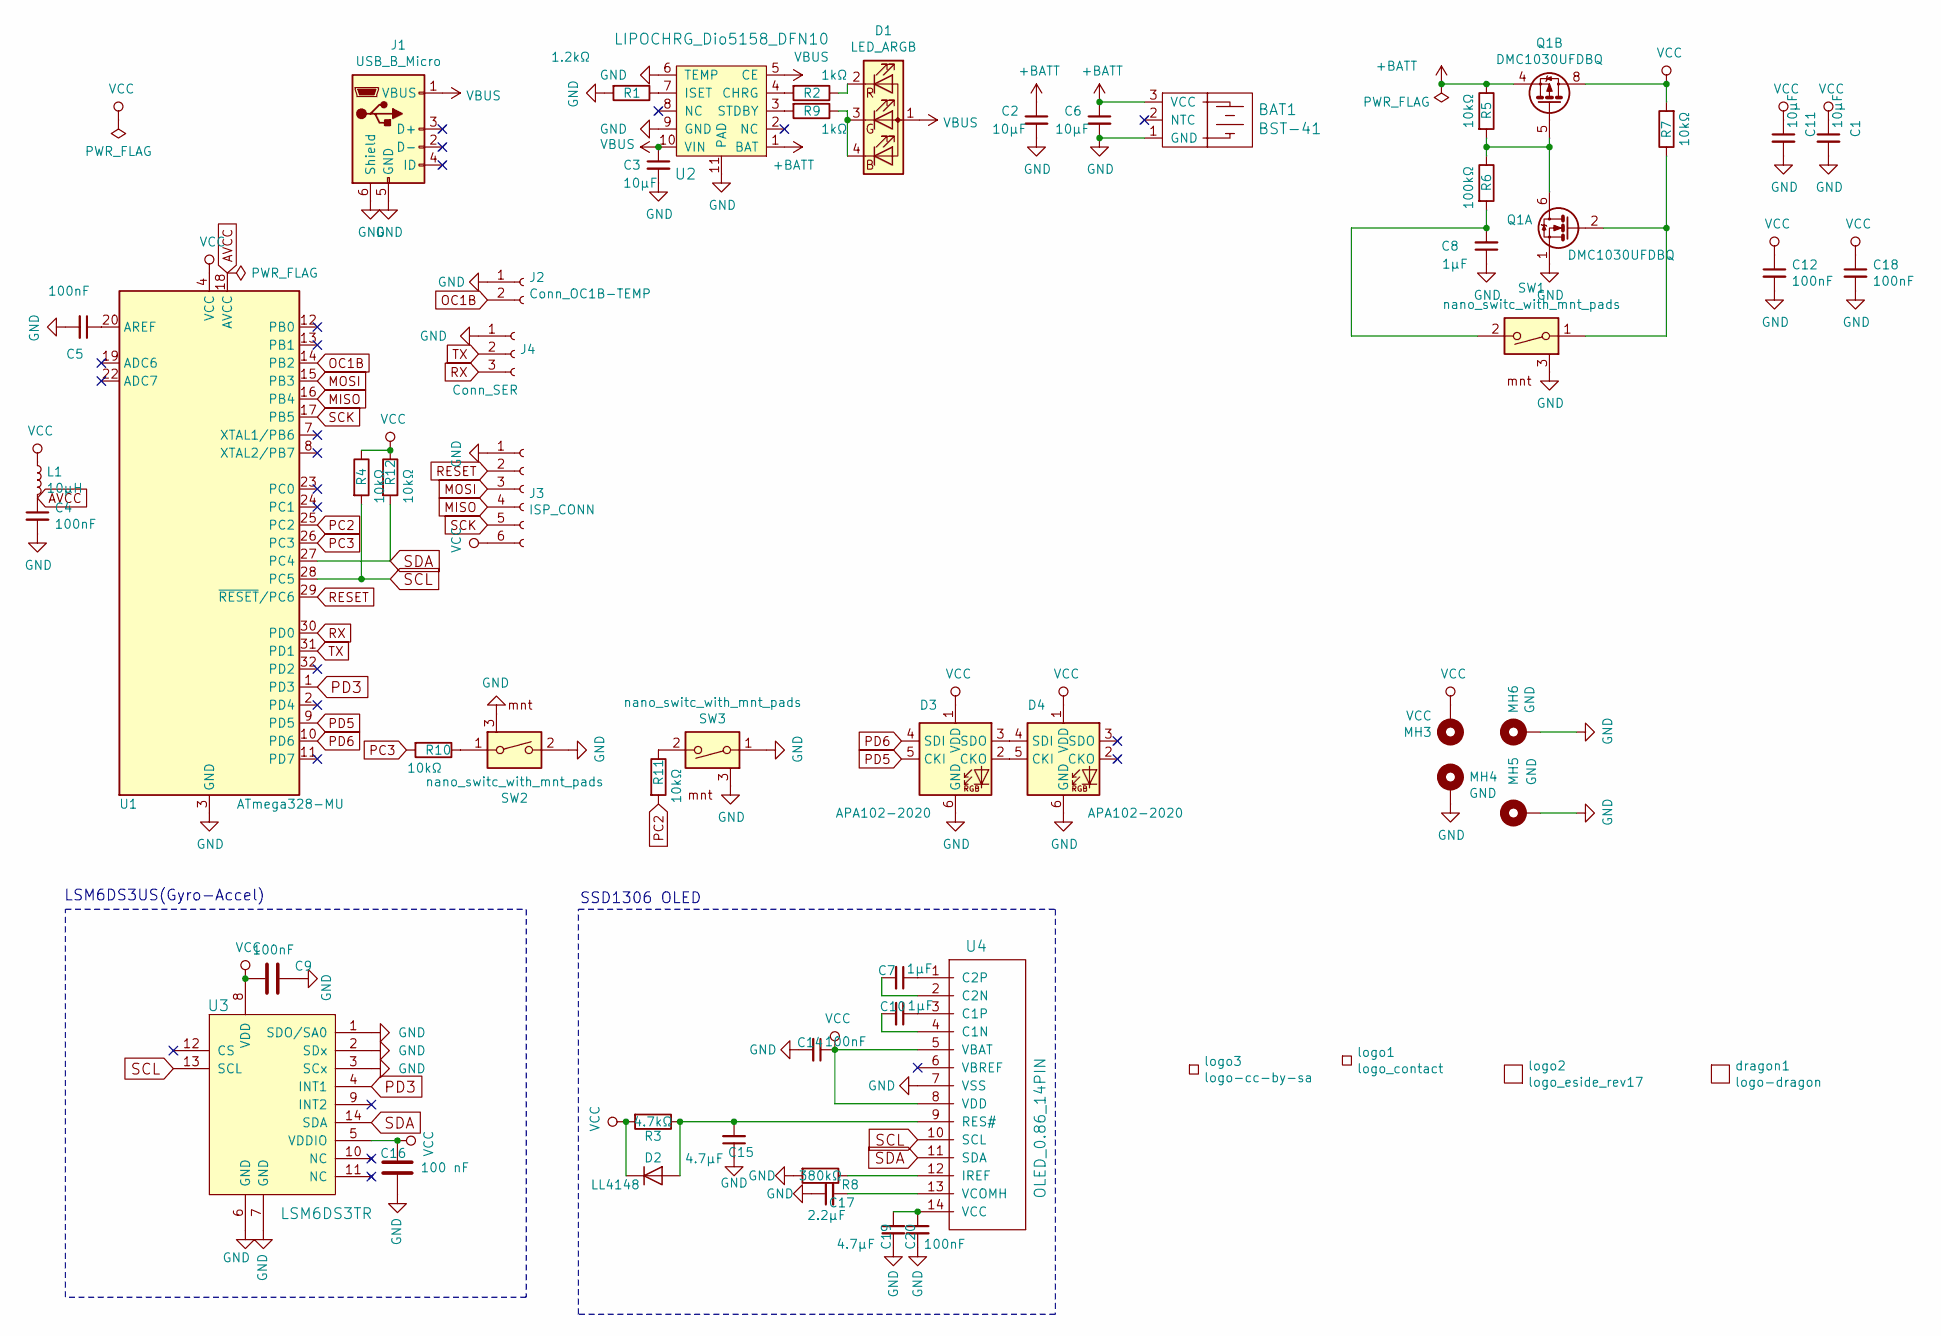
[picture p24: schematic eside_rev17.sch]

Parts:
BAT1: BST-41; CONN_AVX_RT_ANGLE_3pin_2.5mm_pitch
C1, C2, C3, C6, C11: 10µF; C_0805_2012Metric_Pad1.15x1.40mm_HandSolder
C4, C5, C9, C12, C14, C18, C20: 100nF; C_0603_1608Metric_Pad1.05x0.95mm_HandSolder
C7, C8, C10: 1µF; C_0805_2012Metric_Pad1.15x1.40mm_HandSolder
C15, C19: 4.7µF; C_0805_2012Metric_Pad1.15x1.40mm_HandSolder
C16: 100 nF; C_0603_1608Metric_Pad1.05x0.95mm_HandSolder
C17: 2.2µF; C_0805_2012Metric_Pad1.15x1.40mm_HandSolder
D1: LED_ARGB; LED_BARG_1.4x1.5mm
D2: LL4148; D_MiniMELF
D3, D4: APA102-2020; LED-APA102-2020
J1: USB_B_Micro; Conn_USBmicro-B_ebay-side_TH_GROUND
J2: Conn_OC1B-TEMP; PinHeader_1x02_P2.00mm_Vertical
J3: ISP_CONN; Conn_01x06_SMD_2mm
J4: Conn_SER; 01x03_smd_1mmx2mm_pad
L1: 10µH; L_0805_2012Metric_Pad1.15x1.40mm_HandSolder
MH3: VCC; MountingHole_2.2mm_M2_Pad_Via
MH4, MH5, MH6: GND; MountingHole_2.2mm_M2_Pad_Via
Q1: DMC1030UFDBQ; U-DFN2020-6 (Type B)
R1: 1.2kΩ; R_0805_2012Metric
R2, R9: 1kΩ; R_0805_2012Metric
R3: 4.7kΩ; R_0805_2012Metric
R4, R5, R7, R10, R11, R12: 10kΩ; R_0805_2012Metric
R6: 100kΩ; R_0805_2012Metric
R8: 380kΩ; R_0805_2012Metric
SW1, SW2, SW3: nano_switc_with_mnt_pads; white_nano_smd_switch
U1: ATmega328-MU; QFN-32-1EP_5x5mm_P0.5mm_EP3.1x3.1mm
U2: LIPOCHRG_Dio5158_DFN10; DFN-10-1EP_3x3mm_P0.5mm_EP1.55x2.48mm
U3: LSM6DS3TR; LGA-14L_2.5x3mm__LSM6DS3; MPN LSM6DS3TR; Digi-Key_PN 497-15383-1-ND
U4: OLED_0.86_14PIN; OLED_0.86_14pin_i2c
dragon1: logo-dragon; logo_dragon_small
logo1: logo_contact; logo_QR-tag_rev16
logo2: logo_eside_rev17; logo_esiderev17
logo3: logo-cc-by-sa; cc-by-sa

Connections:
+BATT: BAT1.3 (VCC), C2.1, C6.1, Q1.4 (1), R5.1, U2.1 (BAT)
AVCC: C4.1, L1.2, U1.18 (AVCC)
GND: BAT1.1 (GND), C1.2, C2.2, C3.2, C4.2, C5.2, C6.2, C8.1, C9.2, C11.2, C12.2, C14.2, C15.1, C16.2, C17.1, C18.2, C19.2, C20.2, D3.6 (GND), D4.6 (GND), J1.5 (GND), J1.6 (Shield), J2.1, J3.1, J4.1, MH4.1, MH5.1, MH6.1, Q1.1 (S), R1.2, R8.2, SW1.3, SW2.2, SW2.3, SW3.1, SW3.3, U1.3 (GND), U1.5 (GND), U1.21 (GND), U1.33 (GND), U2.6 (TEMP), U2.9 (GND), U2.11 (PAD), U3.1 (SDO/SA0), U3.2 (SDx), U3.3 (SCx), U3.6 (GND), U3.7 (GND), U4.7 (VSS)
MISO: J3.4, U1.16 (PB4)
MOSI: J3.3, U1.15 (PB3)
unnamed: C5.1, U1.20 (AREF)
unnamed: C7.1, U4.1 (C2P)
unnamed: C7.2, U4.2 (C2N)
unnamed: C8.2, R6.2, SW1.2
unnamed: C10.1, U4.3 (C1P)
unnamed: C10.2, U4.4 (C1N)
unnamed: C15.2, D2.2 (A), R3.1, U4.9 (RES#)
unnamed: C17.2, U4.13 (VCOMH)
unnamed: C19.1, C20.1, U4.14 (VCC)
unnamed: D1.2 (RK), R2.1
unnamed: D1.3 (GK), D1.4 (BK), R9.1
unnamed: D3.2 (CKO), D4.5 (CKI)
unnamed: D3.3 (SDO), D4.4 (SDI)
unnamed: Q1.2 (G), R7.1, SW1.1
unnamed: Q1.5 (G), Q1.6 (D), Q1.7 (D), R5.2, R6.1
unnamed: R1.1, U2.7 (ISET)
unnamed: R2.2, U2.4 (CHRG)
unnamed: R8.1, U4.12 (IREF)
unnamed: R9.2, U2.3 (STDBY)
unnamed: R10.1, SW2.1
unnamed: R11.1, SW3.2
OC1B: J2.2, U1.14 (PB2)
PC2: R11.2, U1.25 (PC2)
PC3: R10.2, U1.26 (PC3)
PD3: U1.1 (PD3), U3.4 (INT1)
PD5: D3.5 (CKI), U1.9 (PD5)
PD6: D3.4 (SDI), U1.10 (PD6)
RESET: J3.2, U1.29 (~RESET~/PC6)
RX: J4.3, U1.30 (PD0)
SCK: J3.5, U1.17 (PB5)
SCL: R4.2, U1.28 (PC5), U3.13 (SCL), U4.10 (SCL)
SDA: R12.2, U1.27 (PC4), U3.14 (SDA), U4.11 (SDA)
TX: J4.2, U1.31 (PD1)
VBUS: C3.1, D1.1 (A), J1.1 (VBUS), U2.5 (CE), U2.10 (VIN)
VCC: C1.1, C9.1, C11.1, C12.1, C14.1, C16.1, C18.1, D2.1 (K), D3.1 (VDD), D4.1 (VDD), J3.6, L1.1, MH3.1, Q1.3 (D), Q1.8 (D), R3.2, R4.1, R7.2, R12.1, U1.4 (VCC), U1.6 (VCC), U3.5 (VDDIO), U3.8 (VDD), U4.5 (VBAT), U4.8 (VDD)

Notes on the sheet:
SSD1306 OLED
LSM6DS3US(Gyro-Accel)

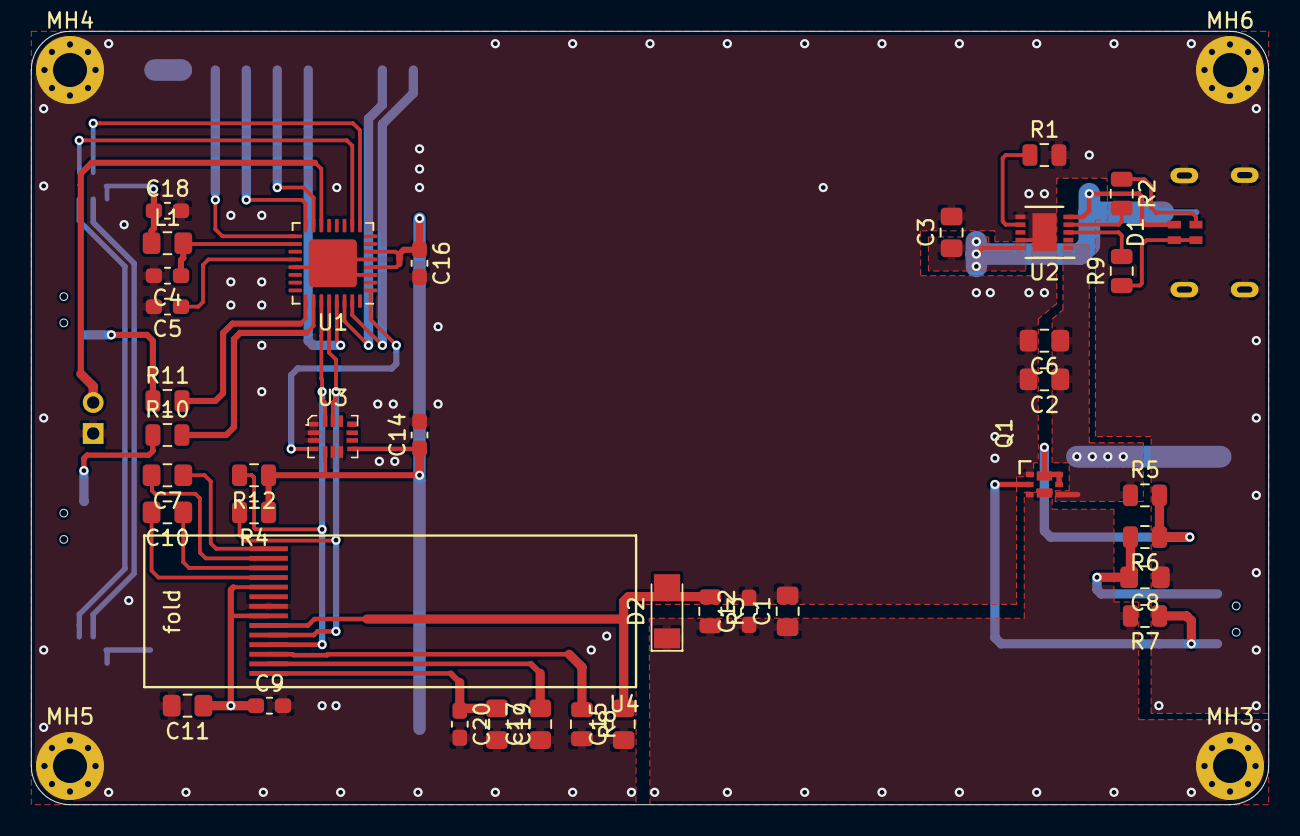
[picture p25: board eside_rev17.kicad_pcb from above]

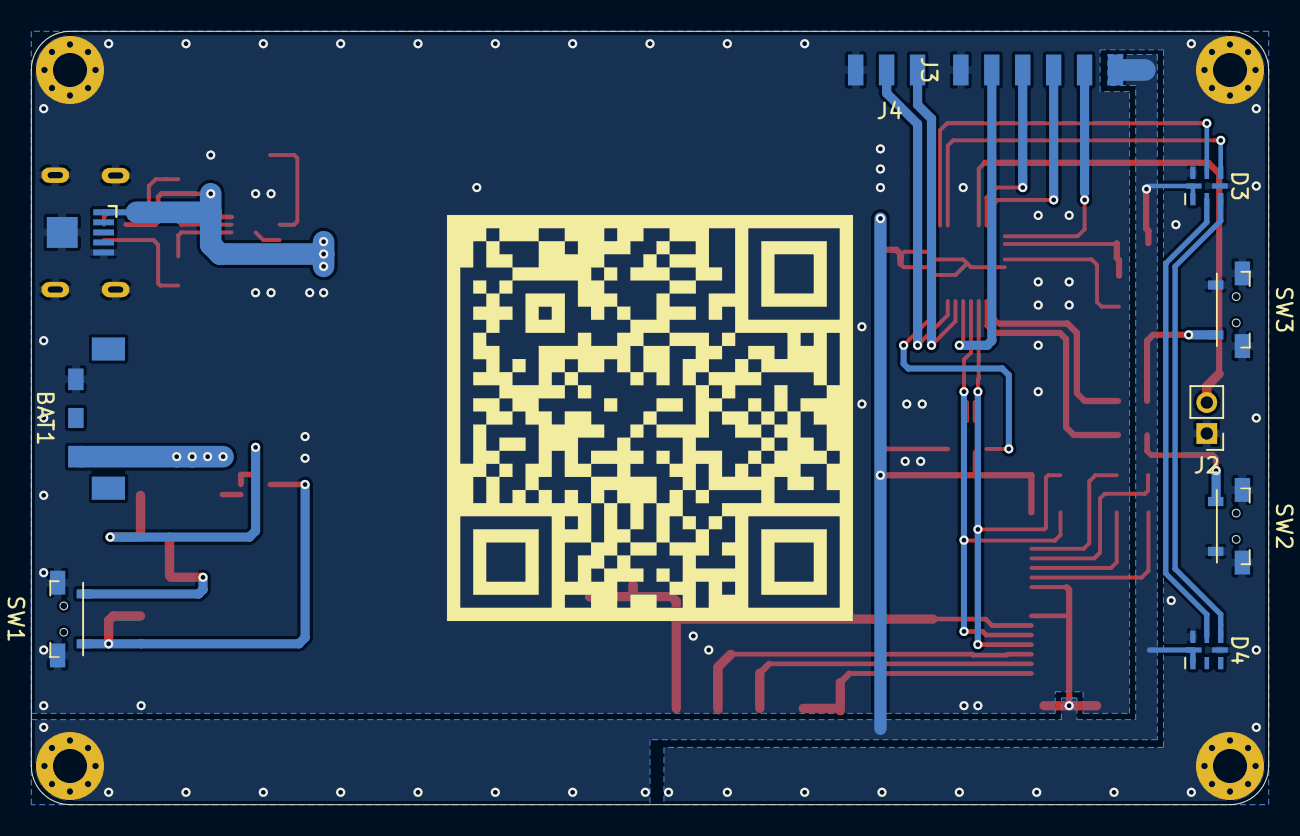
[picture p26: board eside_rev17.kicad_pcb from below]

Board: 2 copper layers, 80.0 x 50.0 mm, 57 parts (11 on the bottom side), 40 nets.

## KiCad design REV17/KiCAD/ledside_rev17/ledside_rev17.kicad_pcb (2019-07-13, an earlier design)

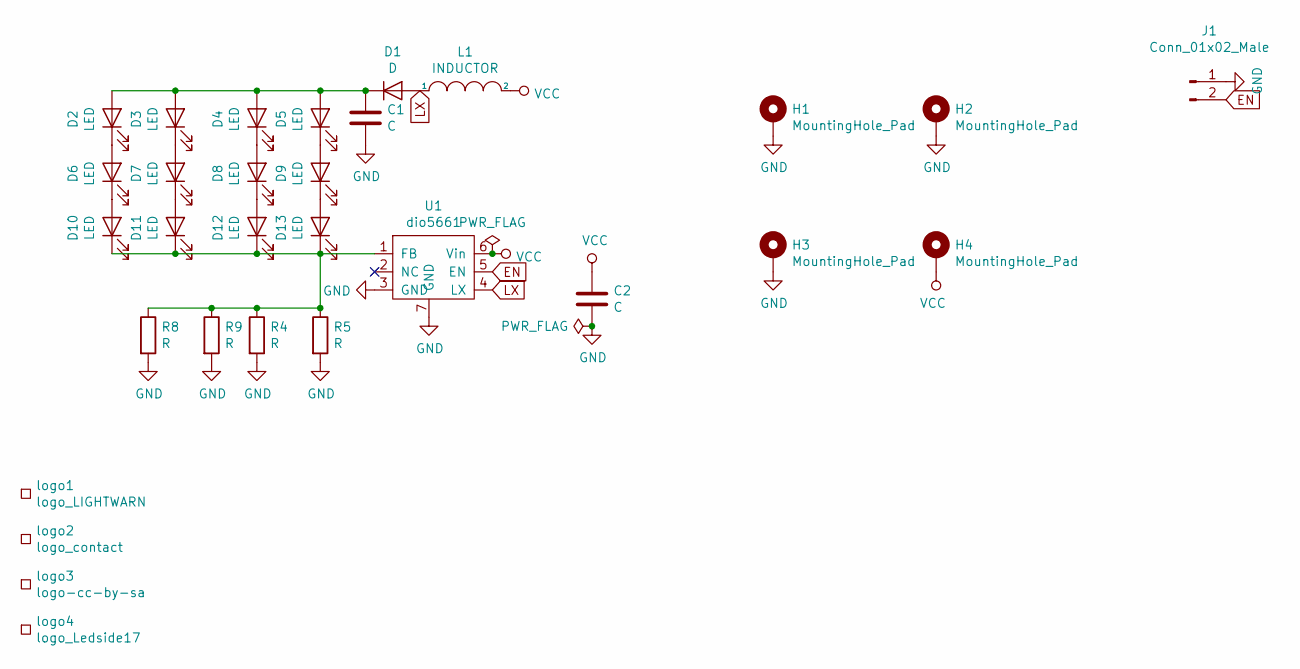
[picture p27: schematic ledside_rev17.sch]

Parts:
C1, C2: C; C_0805_2012Metric
D1: D; D_SOD-123
D2, D3, D4, D5, D6, D7, D8, D9, D10, D11, D12, D13: LED; LED_Cree-J-Series
H1, H2, H3, H4: MountingHole_Pad; MountingHole_2.2mm_M2_Pad_Via
J1: Conn_01x02_Male; PinHeader_1x02_P2.00mm_Vertical
L1: INDUCTOR; L_Taiyo-Yuden_NR-60xx
R4, R5, R8, R9: R; R_1206_3216Metric
U1: dio5661; DFN-6-1EP_2x2mm_P0.65mm_EP1x1.6mm
logo1: logo_LIGHTWARN; logo_light_warn
logo2: logo_contact; logo_QR-tag_rev16
logo3: logo-cc-by-sa; cc-by-sa
logo4: logo_Ledside17; logo_ledsiderev17

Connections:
EN: J1.2, U1.5 (EN)
GND: C1.2, C2.2, H1.1, H2.1, H3.1, J1.1, R4.2, R5.2, R8.2, R9.2, U1.3 (GND), U1.7 (GND)
LX: D1.2 (A), L1.1, U1.4 (LX)
unnamed: C1.1, D1.1 (K), D2.2 (A), D3.2 (A), D4.2 (A), D5.2 (A)
unnamed: D2.1 (K), D6.2 (A)
unnamed: D3.1 (K), D7.2 (A)
unnamed: D4.1 (K), D8.2 (A)
unnamed: D5.1 (K), D9.2 (A)
unnamed: D10.1 (K), D11.1 (K), D12.1 (K), D13.1 (K), R4.1, R5.1, R8.1, R9.1, U1.1 (FB)
unnamed: D6.1 (K), D10.2 (A)
unnamed: D7.1 (K), D11.2 (A)
unnamed: D8.1 (K), D12.2 (A)
unnamed: D9.1 (K), D13.2 (A)
VCC: C2.1, H4.1, L1.2, U1.6 (Vin)

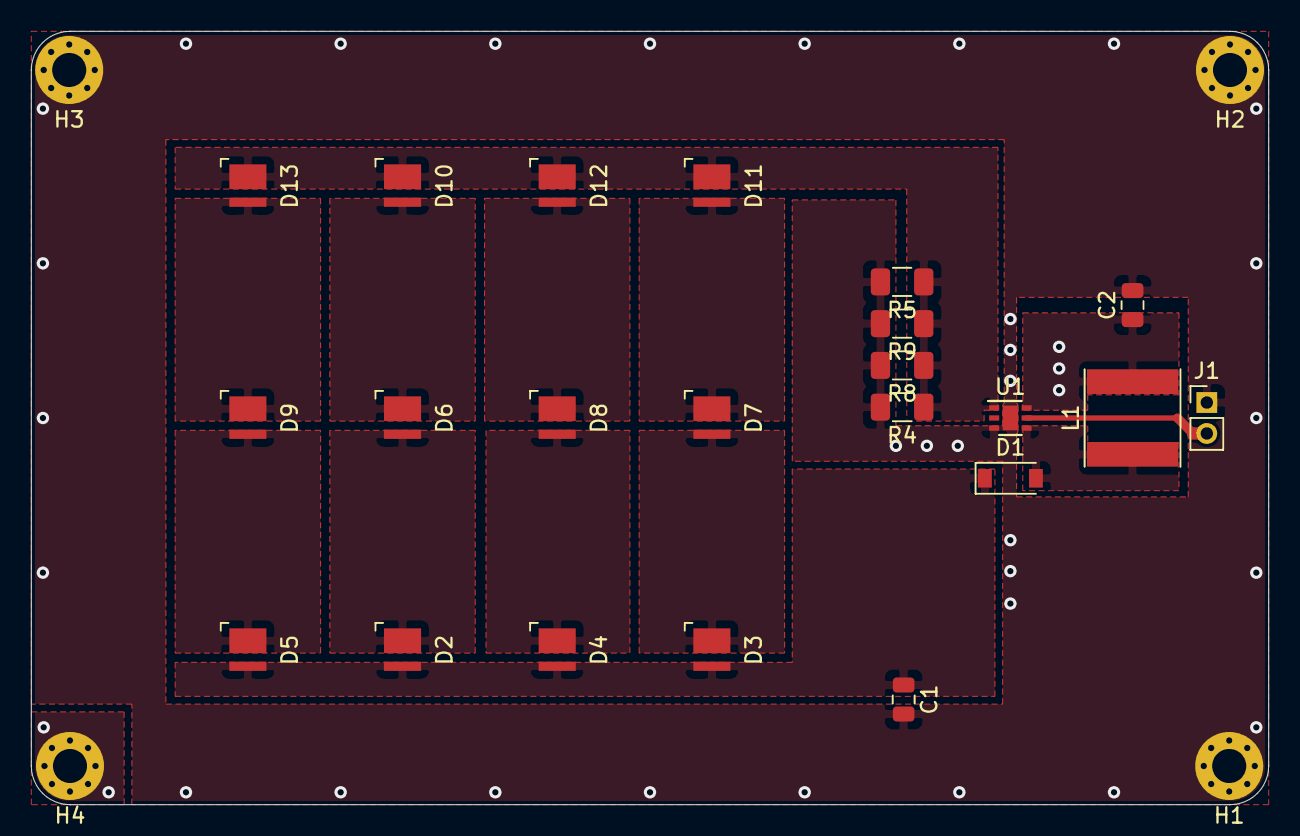
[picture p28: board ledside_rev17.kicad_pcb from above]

Board: 2 copper layers, 80.0 x 50.0 mm, 30 parts (1 on the bottom side), 14 nets.

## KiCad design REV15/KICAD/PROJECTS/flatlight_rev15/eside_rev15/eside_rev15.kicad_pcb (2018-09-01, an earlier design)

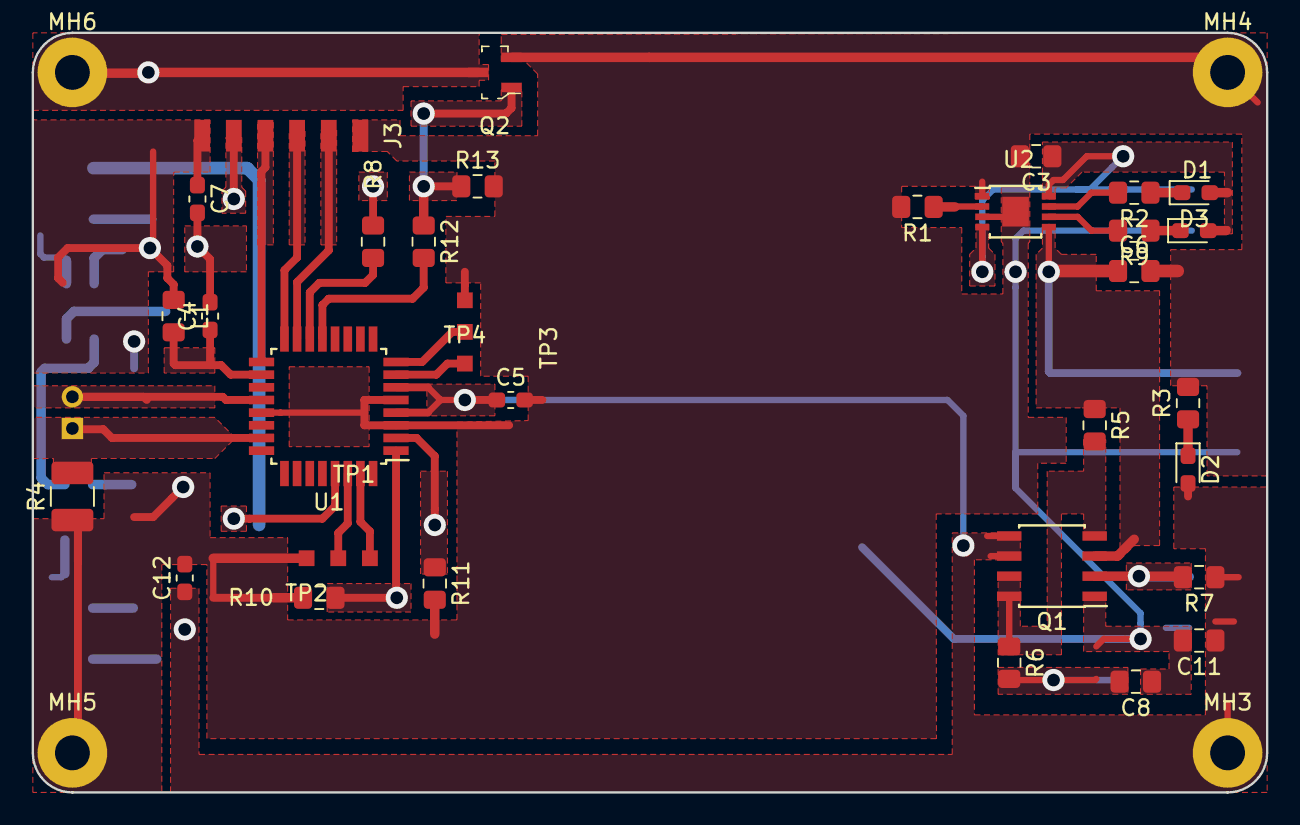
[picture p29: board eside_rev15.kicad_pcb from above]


Board: 2 copper layers, 78.0 x 48.0 mm, 46 parts (8 on the bottom side), 32 nets.

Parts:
BAT1: LIPO_W_NTC; CONN_AVX_RT_ANGLE_3pin_2.5mm_pitch
C3, C6, C11: 10µF; C_0805_2012Metric_Pad1.15x1.40mm_HandSolder
C4, C5, C7, C12: 100nF; C_0603_1608Metric_Pad1.05x0.95mm_HandSolder
C8: 1µF; C_0805_2012Metric_Pad1.15x1.40mm_HandSolder
D1: LED_RED; LED_0603_1608Metric_Pad1.05x0.95mm_HandSolder
D2: LED_PINK; LED_0603_1608Metric_Pad1.05x0.95mm_HandSolder
D3: LED_GREEN; LED_0603_1608Metric_Pad1.05x0.95mm_HandSolder
D4, D8: SK6812MINI; LED_SK6812MINI_PLCC4_3.5x3.5mm_P1.75mm
J1: USB_B_Micro; USB_Micro-B-CHINA
J2: TEMP_SENSOR; PinHeader_1x02_P2.00mm_Vertical
J3: ISP_CONN; Conn_01x06_SMD_2mm
L1: 10µH; L_0805_2012Metric_Pad1.15x1.40mm_HandSolder
MH3: VCC; MountingHole_2.2mm_M2_Pad
MH4, MH5: GND; MountingHole_2.2mm_M2_Pad
MH6: OC1A; MountingHole_2.2mm_M2_Pad
Q1: IRF7343PBF; SOIC-8_3.9x4.9mm_P1.27mm
Q2: IRLML6344TRPBF; SOT-23-3
R1: 1.2kΩ; R_0805_2012Metric_Pad1.15x1.40mm_HandSolder
R2, R3, R8, R9, R12: 1kΩ; R_0805_2012Metric_Pad1.15x1.40mm_HandSolder
R4: 15kΩ; R_1210_3225Metric_Pad1.42x2.65mm_HandSolder
R5, R7, R10, R11: 10kΩ; R_0805_2012Metric_Pad1.15x1.40mm_HandSolder
R6: 100kΩ; R_0805_2012Metric_Pad1.15x1.40mm_HandSolder
R13: 1MΩ; R_0805_2012Metric_Pad1.15x1.40mm_HandSolder
SW1: nano_sw; white_nano_smd_switch
SW2, SW3: SW_DIP_x01; white_nano_smd_switch
TP1: COM; 2_pad_smd_bat_conn
TP2, TP4: TestPoint; 1_pad_smd
TP3: OSC; 2_pad_smd_bat_conn
U1: ATmega88-20AU; TQFP-32_7x7mm_P0.8mm
U2: DIO5158; MSOP-8-1EP_3x3mm_P0.65mm_EP1.68x1.88mm

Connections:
+BATT: BAT1.1, C6.1, Q1.3, R5.1, U2.5
ADC0: J2.1, R4.2, U1.23
AREF: J2.2, U1.20
AVCC: C4.1, L1.2, U1.18
GND: BAT1.3, C3.2, C4.2, C5.2, C6.2, C7.2, C8.1, C11.2, C12.2, D4.2, D8.2, J1.5, J1.6, J3.1, MH4.1, MH5.1, Q1.1, Q2.2, R1.2, R3.2, R4.1, R10.2, R11.2, R13.2, TP2.1, TP4.1, U1.3, U1.5, U1.21, U2.1, U2.3, U2.9
MISO: J3.3, U1.16
MOSI: J3.2, U1.15
unnamed: C8.2, R6.2, SW1.1
unnamed: D1.1, R2.1
unnamed: D2.1, R3.1
unnamed: D3.1, R9.1
unnamed: D4.3, D8.1
unnamed: D8.3, R8.2
unnamed: MH6.1, Q2.3
unnamed: Q1.2, R7.2, SW1.2
unnamed: Q1.4, Q1.7, Q1.8, R5.2, R6.1
unnamed: Q2.1, R12.1, R13.1
unnamed: R1.1, U2.2
unnamed: R2.2, U2.7
unnamed: R9.2, U2.6
OC1A: R12.2, U1.13
OC1B: R8.1, U1.14
OSC_N: TP3.1, U1.7
OSC_P: TP3.2, U1.8
PD3: R10.1, SW2.2, U1.1
PD4: R11.1, SW3.1, U1.2
RESET: J3.5, U1.29
RX: TP1.2, U1.30
SCK: J3.4, U1.17
TX: TP1.1, U1.31
VBUS: C3.1, D1.2, D3.2, J1.1, U2.4, U2.8
VCC: C5.1, C7.1, C11.1, C12.1, D2.2, D4.4, D8.4, J3.6, L1.1, MH3.1, Q1.5, Q1.6, R7.1, SW2.1, SW3.2, U1.4, U1.6

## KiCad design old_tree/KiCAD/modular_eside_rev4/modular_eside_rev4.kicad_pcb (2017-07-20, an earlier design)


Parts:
BAT1: LIPO_W_NTC; conn_BST-41_spring_contact
C1, C2: 10µF; C_0805
C3: 1µF; C_0805
C5, C6: 10µF; C_1206
C7: 100nF_decoupling; C_0805
C8: 100nF; C_0805
D1: RED; LED_0603
D2: GREEN; LED_0603
D3: CHRG_IND_BRTGREEN; LED_0603
D4: CHRG_IND_GREEN; LED_0603
D5: CHRG_IND_YELLOW; LED_0603
D6: CHRG_IND_ORANGE; LED_0603
D7: CHRG_IND_RED; LED_0603
D8: TOPLED_GRN; LED_1206
D9: RED_TMPWRN; LED_0603
D10, D11, D12, D13, D14: LED; LED_CREE_XRC_7x9mm
D15, D16, D17, D18, D19, D20, D21, D22, D23, D24, D25, D26, D27, D28, D29, D30: LED; LED_0805_HandSoldering
J1: USB_Micro_Jack; USB_Micro-B-CHINA
J2: CONN_ES_ISP1; 3pin_through_conn
J3: CONN_ES_ISP2; 3pin_through_conn
J4: CONN_ES_LSGND; 3pin_through_conn
J5: CONN_LS_LSGND; 3pin_through_conn
J6: CONN_ES_VCC; 3pin_through_conn
J7: CONN_LS_VCC; 3pin_through_conn
J8: CONN_ES_NTC; 3pin_through_conn
J9: CONN_LS_NTC; 3pin_through_conn
J10, J11, J12, J13: CONN_BOARDCONN; 3pin_through_conn
L1: 10µH; L_1206
Q1: IRF7319; SOIC-8_3.9x4.9mm_Pitch1.27mm
Q3, Q4: IRLML6244; SOT-23
R1: 1.2KΩ; R_0805
R2, R3, R18, R19: 1KΩ; R_0805
R4, R6, R22: 100KΩ; R_0805
R5, R7: 10KΩ; R_0805
R8, R21, R23: 237Ω; R_0805
R17: 15KΩ; R_1210
R24: 15K NTC; R_0805
RN1: R_Pack_220Ω; R_Array_Convex_4x0603
SW1: SW_PWR; square_red_button_mount_6.3mm
SW2: SW_MODE; square_red_button_mount_6.3mm
U1: TP4056; SOIC-8-1EP_3.9x4.9mm_Pitch1.27mm
U3: ATMEGA8A-AU; TQFP-32_7x7mm_Pitch0.8mm_Pins0.45

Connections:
+BATT: BAT1.1 (VCC), C2.1, Q1.3 (1), R5.1, U1.5 (BAT)
ADC0: J8.1, R17.2, U3.23 ((ADC0)PC0)
AREF: J8.3, U3.20 (AREF)
AVCC: C8.2, L1.2, U3.18 (AVCC)
CHRG: R2.2, U1.7 (CHRG)
GND: BAT1.2 (GND), C1.2, C2.2, C3.2, C7.2, C8.1, D3.1 (K), D4.1 (K), D5.1 (K), D6.1 (K), D7.1 (K), D8.1 (K), D9.1 (K), J1.4 (GND), J1.5 (Shield), J3.1, Q1.1 (S), Q3.2 (S), Q4.2 (S), R1.1, R6.2, R17.1, R22.2, U1.1 (TEMP), U1.3 (GND), U1.9 (GND), U3.3 (GND), U3.5 (GND), U3.21 (AGND)
LED_ES_GND: C6.2, J10.1, J10.2, J10.3, Q4.3 (D)
LED_LS_GND: C5.2, J4.1, J4.2, J4.3, Q3.3 (D)
MISO: J2.1, U3.16 ((MISO)PB4)
MOSI: J2.2, U3.15 ((MOSI/OC2)PB3)
unnamed: C3.1, R4.2, SW1.2
unnamed: D1.1 (K), R2.1
unnamed: D2.1 (K), R3.1
unnamed: D3.2 (A), RN1.8 (R1.2)
unnamed: D4.2 (A), RN1.7 (R2.2)
unnamed: D5.2 (A), RN1.6 (R3.2)
unnamed: D6.2 (A), RN1.5 (R4.2)
unnamed: D7.2 (A), R8.2
unnamed: D8.2 (A), R21.1
unnamed: D9.2 (A), R23.1
unnamed: D10.1 (K), D11.1 (K), D12.1 (K), D13.1 (K), D14.1 (K), J5.1, J5.2, J5.3
unnamed: D10.2 (A), D11.2 (A), D12.2 (A), D13.2 (A), D14.2 (A), J7.1, J7.2, J7.3
unnamed: D15.1 (K), D16.1 (K), D17.1 (K), D18.1 (K), D19.1 (K), D20.1 (K), D21.1 (K), D22.1 (K), D23.1 (K), D24.1 (K), D25.1 (K), D26.1 (K), D27.1 (K), D28.1 (K), D29.1 (K), D30.1 (K), J11.1, J11.2, J11.3
unnamed: D15.2 (A), D16.2 (A), D17.2 (A), D18.2 (A), D19.2 (A), D20.2 (A), D21.2 (A), D22.2 (A), D23.2 (A), D24.2 (A), D25.2 (A), D26.2 (A), D27.2 (A), D28.2 (A), D29.2 (A), D30.2 (A), J13.1, J13.2, J13.3
unnamed: J9.1, R24.2
unnamed: J9.3, R24.1
unnamed: Q1.2 (G), R7.1, SW1.1
unnamed: Q1.4 (G), Q1.7, Q1.8 (D), R4.1, R5.2
unnamed: Q3.1 (G), R18.1
unnamed: Q4.1 (G), R19.1
OC1A: R18.2, U3.13 ((OC1A)PB1)
OC1B: R19.2, U3.14 ((~SS~/OC1B)PB2)
PC1: R8.1, U3.24 ((ADC1)PC1)
PC2: RN1.4 (R4.1), U3.25 ((ADC2)PC2)
PC3: RN1.3 (R3.1), U3.26 ((ADC3)PC3)
PC4: RN1.2 (R2.1), U3.27 ((ADC4/SDA)PC4)
PC5: RN1.1 (R1.1), U3.28 ((ADC5/SCL)PC5)
PD0: R22.1, SW2.2, U3.30 ((RXD)PD0)
PD1: R23.2, U3.31 ((TXD)PD1)
PD2: U3.32 ((INT0)PD2)
PRG: R1.2, U1.2 (PRG)
RESET: J3.2, U3.29 (PC6(~RESET~))
SCK: J3.3, U3.17 ((SCK)PB5)
STDBY: R3.2, U1.6 (STDBY)
VCC: C5.1, C6.1, C7.1, J2.3, J6.1, J6.2, J6.3, J12.1, J12.2, J12.3, L1.1, Q1.5, Q1.6 (D), R6.1, R7.2, R21.2, SW2.1, U3.4 (VCC), U3.6 (VCC)
VSS: C1.1, D1.2 (A), D2.2 (A), J1.1 (VBUS), U1.4 (VCC), U1.8 (CE)

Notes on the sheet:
Battery charge circuit
Soft latch
Microcontroller and peripherial
LEDSIDE
ESIDE_CONNECTORS
Power and Temp Indicator
ADC Noise Canceler (obsolete)
Modeswitch
ISP Connector
ADC Resistor (Temp)
MC decoupling cap
LED Switching facility
Battery charge indicator



Board: 2 copper layers, 170.0 x 49.0 mm, 75 parts (14 on the bottom side), 45 nets.

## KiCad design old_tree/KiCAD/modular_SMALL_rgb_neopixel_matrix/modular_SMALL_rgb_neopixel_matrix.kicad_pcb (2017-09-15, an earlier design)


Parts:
C1, C2, C3, C4, C5, C7, C8, C9, C10, C11, C13, C14, C15, C16, C17, C19, C20, C21, C22, C23, C25, C26, C27, C28, C29, C31, C32, C33, C34, C35, C37, C38, C39, C40, C41, C43, C44, C45, C46, C47: 100nF; C_1206
D1, D2, D3: CREE_XP; LED_Cree-XP_x
J1, J2, J4, J5: CONN_01X03; 3pin_through_conn
J3: CONN_01X08; 1x08_Pitch2.00mm_Bigpad
R1: 15KΩ_NTC; R_0805
R2, R3: 0Ω_Bridge; R_1206
U1, U2, U3, U4, U5, U6, U7, U8, U9, U10, U11, U12, U13, U14, U15, U16, U17, U18, U19, U20, U21, U22, U23, U24, U25, U26, U27, U28, U29, U30, U31, U32, U33, U34, U35, U36, U37, U38, U39, U40, U41, U42, U43, U44, U45, U46, U47, U48: RGB_ws2812_3535; SK6812_MINI_3535

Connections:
GND: C1.2, C2.2, C3.2, C4.2, C5.2, C7.2, C8.2, C9.2, C10.2, C11.2, C13.2, C14.2, C15.2, C16.2, C17.2, C19.2, C20.2, C21.2, C22.2, C23.2, C25.2, C26.2, C27.2, C28.2, C29.2, C31.2, C32.2, C33.2, C34.2, C35.2, C37.2, C38.2, C39.2, C40.2, C41.2, C43.2, C44.2, C45.2, C46.2, C47.2, J5.1, J5.2, J5.3, U1.2 (GND), U2.2 (GND), U3.2 (GND), U4.2 (GND), U5.2 (GND), U6.2 (GND), U7.2 (GND), U8.2 (GND), U9.2 (GND), U10.2 (GND), U11.2 (GND), U12.2 (GND), U13.2 (GND), U14.2 (GND), U15.2 (GND), U16.2 (GND), U17.2 (GND), U18.2 (GND), U19.2 (GND), U20.2 (GND), U21.2 (GND), U22.2 (GND), U23.2 (GND), U24.2 (GND), U25.2 (GND), U26.2 (GND), U27.2 (GND), U28.2 (GND), U29.2 (GND), U30.2 (GND), U31.2 (GND), U32.2 (GND), U33.2 (GND), U34.2 (GND), U35.2 (GND), U36.2 (GND), U37.2 (GND), U38.2 (GND), U39.2 (GND), U40.2 (GND), U41.2 (GND), U42.2 (GND), U43.2 (GND), U44.2 (GND), U45.2 (GND), U46.2 (GND), U47.2 (GND), U48.2 (GND)
unnamed: J3.1, R2.2
unnamed: J3.2, R3.2
unnamed: R1.1, R2.1
unnamed: R1.2, R3.1
unnamed: U1.3 (DIN), U2.1 (DOUT)
unnamed: U2.3 (DIN), U3.1 (DOUT)
unnamed: U3.3 (DIN), U4.1 (DOUT)
unnamed: U4.3 (DIN), U5.1 (DOUT)
unnamed: U5.3 (DIN), U6.1 (DOUT)
unnamed: U6.3 (DIN), U7.1 (DOUT)
unnamed: U7.3 (DIN), U8.1 (DOUT)
unnamed: U8.3 (DIN), U9.1 (DOUT)
unnamed: U9.3 (DIN), U10.1 (DOUT)
unnamed: U10.3 (DIN), U11.1 (DOUT)
unnamed: U11.3 (DIN), U12.1 (DOUT)
unnamed: U12.3 (DIN), U13.1 (DOUT)
unnamed: U13.3 (DIN), U14.1 (DOUT)
unnamed: U14.3 (DIN), U15.1 (DOUT)
unnamed: U15.3 (DIN), U16.1 (DOUT)
unnamed: U16.3 (DIN), U17.1 (DOUT)
unnamed: U17.3 (DIN), U18.1 (DOUT)
unnamed: U18.3 (DIN), U19.1 (DOUT)
unnamed: U19.3 (DIN), U20.1 (DOUT)
unnamed: U20.3 (DIN), U21.1 (DOUT)
unnamed: U21.3 (DIN), U22.1 (DOUT)
unnamed: U22.3 (DIN), U23.1 (DOUT)
unnamed: U23.3 (DIN), U24.1 (DOUT)
unnamed: U24.3 (DIN), U25.1 (DOUT)
unnamed: U25.3 (DIN), U26.1 (DOUT)
unnamed: U26.3 (DIN), U27.1 (DOUT)
unnamed: U27.3 (DIN), U28.1 (DOUT)
unnamed: U28.3 (DIN), U29.1 (DOUT)
unnamed: U29.3 (DIN), U30.1 (DOUT)
unnamed: U30.3 (DIN), U31.1 (DOUT)
unnamed: U31.3 (DIN), U32.1 (DOUT)
unnamed: U32.3 (DIN), U33.1 (DOUT)
unnamed: U33.3 (DIN), U34.1 (DOUT)
unnamed: U34.3 (DIN), U35.1 (DOUT)
unnamed: U35.3 (DIN), U36.1 (DOUT)
unnamed: U36.3 (DIN), U37.1 (DOUT)
unnamed: U37.3 (DIN), U38.1 (DOUT)
unnamed: U38.3 (DIN), U39.1 (DOUT)
unnamed: U39.3 (DIN), U40.1 (DOUT)
unnamed: U40.3 (DIN), U41.1 (DOUT)
unnamed: U41.3 (DIN), U42.1 (DOUT)
unnamed: U42.3 (DIN), U43.1 (DOUT)
unnamed: U43.3 (DIN), U44.1 (DOUT)
unnamed: U44.3 (DIN), U45.1 (DOUT)
unnamed: U45.3 (DIN), U46.1 (DOUT)
unnamed: U46.3 (DIN), U47.1 (DOUT)
unnamed: U47.3 (DIN), U48.1 (DOUT)
OCA_1: J2.1, J2.2, J2.3, U48.3 (DIN)
PWM_1: D1.1 (K), D2.1 (K), D3.1 (K), J4.1, J4.2, J4.3
VCC: C1.1, C2.1, C3.1, C4.1, C5.1, C7.1, C8.1, C9.1, C10.1, C11.1, C13.1, C14.1, C15.1, C16.1, C17.1, C19.1, C20.1, C21.1, C22.1, C23.1, C25.1, C26.1, C27.1, C28.1, C29.1, C31.1, C32.1, C33.1, C34.1, C35.1, C37.1, C38.1, C39.1, C40.1, C41.1, C43.1, C44.1, C45.1, C46.1, C47.1, D1.2 (A), D2.2 (A), D3.2 (A), J1.1, J1.2, J1.3, U1.4 (VCC), U2.4 (VCC), U3.4 (VCC), U4.4 (VCC), U5.4 (VCC), U6.4 (VCC), U7.4 (VCC), U8.4 (VCC), U9.4 (VCC), U10.4 (VCC), U11.4 (VCC), U12.4 (VCC), U13.4 (VCC), U14.4 (VCC), U15.4 (VCC), U16.4 (VCC), U17.4 (VCC), U18.4 (VCC), U19.4 (VCC), U20.4 (VCC), U21.4 (VCC), U22.4 (VCC), U23.4 (VCC), U24.4 (VCC), U25.4 (VCC), U26.4 (VCC), U27.4 (VCC), U28.4 (VCC), U29.4 (VCC), U30.4 (VCC), U31.4 (VCC), U32.4 (VCC), U33.4 (VCC), U34.4 (VCC), U35.4 (VCC), U36.4 (VCC), U37.4 (VCC), U38.4 (VCC), U39.4 (VCC), U40.4 (VCC), U41.4 (VCC), U42.4 (VCC), U43.4 (VCC), U44.4 (VCC), U45.4 (VCC), U46.4 (VCC), U47.4 (VCC), U48.4 (VCC)


Board: 2 copper layers, 77.5 x 48.0 mm, 99 parts (0 on the bottom side), 55 nets.

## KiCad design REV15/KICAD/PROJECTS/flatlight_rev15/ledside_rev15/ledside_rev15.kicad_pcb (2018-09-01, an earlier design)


Board: 2 copper layers, 78.0 x 48.0 mm, 13 parts (0 on the bottom side), 5 nets.

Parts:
D1, D2, D3, D4: LED; LED_osram_oslon_ssl_powerled
J1: Conn_01x02_Male; PinHeader_1x02_P2.00mm_Vertical
MH1: VCC; MountingHole_2.2mm_M2_Pad
MH2, MH4: GND; MountingHole_2.2mm_M2_Pad
MH3: SOURCE; MountingHole_2.2mm_M2_Pad
R1: R; R_0805_2012Metric_Pad1.15x1.40mm_HandSolder
TP1: VCC; 1_pad_smd
TP2: SOURCE; 1_pad_smd
TP3: THERM; 1_pad_smd

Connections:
GND: D1.1, D2.1, D3.1, D4.1, MH3.1, TP2.1
unnamed: D4.3, J1.1, R1.1
unnamed: J1.2, R1.2
VCC: D1.2, D2.2, D3.2, D4.2, MH1.1, TP1.1
therm: D1.3, D2.3, D3.3, TP3.1

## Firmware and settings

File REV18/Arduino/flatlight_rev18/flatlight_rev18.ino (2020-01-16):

/* flatlight revision 18
 *  by http://github.com/specs32 (sorry !)
 *  atmega 328 - 8 MHZ intern OSC -> avrdude -e -c [PROGRAMMER] -pm328 -B10 -U lfuse:w:0xe2:m -U hfuse:w:0xd9:m -U efuse:w:0xff:m
 *  2 x APA102 - 2020  status-leds
 *  2 Buttons
 *  1 IMU
 *  8 Cree J-Series HighPower
 *  4 Cree XP-E
 *
 */


// INDICATORS
#include <FastLED.h>                                            // please check out https://github.com/FastLED/FastLED for license and such
#define LED_DT 6                                             // Serial data pin for WS2812 or WS2801.
#define LED_CK 5                                             // Serial clock pin for WS2801 or APA102.
#define COLOR_ORDER BGR                                       // Are they GRB for WS2812 and GBR for APA102
#define LED_TYPE APA102                                       // What kind of strip are you using? WS2812, APA102. . .
#define NUM_LEDS 2
struct CRGB leds[NUM_LEDS];                                   // Initialize our LED array.
CRGBPalette16 currentPalette;                                 // Palette definitions
CRGBPalette16 targetPalette;
TBlendType currentBlending = LINEARBLEND;
uint8_t batled = 1;                                           //name the pixels
uint8_t briled = 0;
uint8_t max_bright = 255;                                     // Overall brightness definition. It can be changed on the fly.

// TIMERS
#include <SimpleTimer.h>                                      // out of the arduino repo
SimpleTimer TEMPCHECK;
SimpleTimer BATCHECK;
SimpleTimer PWMCHECK;

// IMU
#include "SparkFunLSM6DS3.h"                                  // please check out https://github.com/sparkfun/SparkFun_LSM6DS3_Arduino_Library for license and such
LSM6DS3 myIMU( I2C_MODE, 0x6A );                              //I2C device address 0x6A

// INT 1
const int int1Pin = 2;                                        //Use pin 2 for int.0 on uno
uint8_t int1Status = 0;
uint8_t t_toggle = 0;                                         // tap toggle
uint8_t t_toggle_last = 0;
uint8_t dt_toggle = 0;                                        // dt toggle
uint8_t dt_toggle_last = 0;

// INT 2
const int int2Pin = 3;                                        //Use pin 2 for int.0 on uno
uint8_t int2Status = 0;
uint8_t wu_toggle = 0;

// BUTTON PINS
const int BUTTON_UP = 17;                                    // define the up button pin
const int BUTTON_DOWN = 16;                                  // define the down button pin

// LED PINS
const int LIGHT = 10;                                         // PowerLED PWM control. (OC1B // PB2 // PIN10)
const int BEAM = 9;                                           // PowerLED  PWM control. (OC1A // PB1 // PIN9)

// CONSTRAINS to the leds
uint8_t LIGHTPWMLIMIT = 150;                                  // PWMLIMIT FOR THE FULLY CHARGED LIPO !!!! 
uint8_t BEAMPWMLIMIT = 150;                                   // PWMLIMIT FOR THE FULLY CHARGED LIPO !!!! 
uint16_t LIGHTMAXTEMP = 40;                                   // (when to STEP down !) Depends very strong on the thermal connection between LED and NTC... 40 works for me here atm.
uint16_t BEAMMAXTEMP = 45;                                    // these leds have a heatsink pad coupled to the ntc (on ledside no. 2), temps will read higher !
uint8_t LIGHTCRITTEMP = 60;                                   // (when to SHUT down  !) compensate for overshoot ...
uint8_t BEAMCRITTEMP = 60;
uint16_t Vf_BEAM = 2800;                                      // led max. forward voltage
uint16_t Vf_LIGHT = 3000;    
uint8_t LIGHTSTATE = 0;                                       // LIGHT @ 1-(PWMLIMIT)
uint8_t BEAMSTATE = 0;               

// LIPO Setup
uint16_t bat_full = 4385;                                     // Lipo charged
uint16_t bat_empty = 2750;                                    // Lipo discharged 

// BUTTON UP
boolean up_lastReading = HIGH;                                // button read value
long up_onTime = 0;                                           // button read ontime
long up_lastSwitchTime = 0;                                   // button switchtime value
uint8_t up_hold = 0;                                          // button hold value
uint8_t up_single = 0;                                        // button single press value

// BUTTON DOWN
boolean down_lastReading = HIGH;                              // button read value
long down_onTime = 0;                                         // button read ontime
long down_lastSwitchTime = 0;                                 // button switchtime value
uint8_t down_hold = 0;                                        // button hold value
uint8_t down_single = 0;

// BUTTON SETTINGS
const uint8_t bounceTime = 50;                                // define button debounce
const uint8_t holdTime = 250;                                 // define button hold time
const uint16_t doubleTime = 700;                              // define button doubleclick time

// PLASMA FUNCTION
#define qsubd(x, b)  ((x>b)?b:0)                              // Digital unsigned subtraction macro. if result <0, then => 0. Otherwise, take on fixed value.
#define qsuba(x, b)  ((x>b)?x-b:0)                            // Analog Unsigned subtraction macro. if result <0, then => 0

// SETUP SETUP SETUP SETUP SETUP SETUP SETUP SETUP SETUP SETUP SETUP SETUP SETUP SETUP SÄÄÄTUUUUUUUPPPPP
void setup() {
  
  // grace
  delay(500);
  
  // debug
  Serial.begin(9600);

  // setup pixels
  LEDS.addLeds<LED_TYPE, LED_DT, LED_CK, COLOR_ORDER>(leds, NUM_LEDS);
  FastLED.setBrightness(max_bright);
  currentPalette = OceanColors_p;

  // timers
  TEMPCHECK.setInterval(53, CHECKTEMP);                       // call  every x milliseconds
  BATCHECK.setInterval(3001, BATDISP);               
  PWMCHECK.setInterval(557, SETPWM);               

  // IMU SETUP
  myIMU.begin();                                                        // This is the config for a LSM6DSM ! (check datasheet which registers to pull !)
  myIMU.writeRegister( LSM6DS3_ACC_GYRO_CTRL1_XL, 0x61);
  myIMU.writeRegister( LSM6DS3_ACC_GYRO_CTRL8_XL, 0x04);
  myIMU.writeRegister( LSM6DS3_ACC_GYRO_TAP_CFG1, 0x9E );               
  myIMU.writeRegister( LSM6DS3_ACC_GYRO_TAP_THS_6D, 0x8C );
  myIMU.writeRegister( LSM6DS3_ACC_GYRO_INT_DUR2, 0x7F );              
  myIMU.writeRegister( LSM6DS3_ACC_GYRO_WAKE_UP_THS, 0x81 );            // threshold settings for taps and wakeup
  myIMU.writeRegister( LSM6DS3_ACC_GYRO_WAKE_UP_DUR, 0x0F );            // threshold settings for sleep and wakeup 
  myIMU.writeRegister( LSM6DS3_ACC_GYRO_MD1_CFG, 0x48 );                // interrupt 1 event config (tap and wakeup) // 48 for tap
  myIMU.writeRegister( LSM6DS3_ACC_GYRO_MD2_CFG, 0x20 );                // interrupt 2 event config (inactivity and wakeup)

  // setting up the interrupt pins
  pinMode(int1Pin, INPUT);                                       
  attachInterrupt(digitalPinToInterrupt(int1Pin), int1ISR, RISING); 
  pinMode(int2Pin, INPUT);                                      
  attachInterrupt(digitalPinToInterrupt(int2Pin), int2ISR, RISING);

  //define BUTTON AND LIGHT PIN Modes
  pinMode(BUTTON_UP, INPUT_PULLUP);
  pinMode(BUTTON_DOWN, INPUT_PULLUP);
  pinMode(LIGHT, OUTPUT);
  pinMode(BEAM, OUTPUT);

  // FastPWM 9-bit (something is there about it ... hmmm cap on the fet ?)
  TCCR1A =  _BV(COM1A1) | _BV(COM1B1) | _BV(WGM11); // _BV(WGM10) |
  TCCR1B = _BV(CS10) | _BV(WGM12);

} // setup end

// LOOP LOOP LOOP LOOP LOOP LOOP LOOP LOOP LOOP LOOP LOOP LOOP LOOP LOOP LOOP OF INFINITY
void loop() {
  
  // TIMERS
  TEMPCHECK.run();
  BATCHECK.run();
  PWMCHECK.run();

  // INT1 TAP
  if( int1Status > 0 ) {
      delay(300);
      // TAP
      if( int1Status == 1 ) {
//        Serial.println("T");
        if (t_toggle == 0){
        t_toggle = 1;
        } else if (t_toggle =! 0){
        t_toggle = 0;
        }
      }
      // DOuBLE TAP
      if( int1Status > 1 )  {
//        Serial.println("DT");
        if (dt_toggle == 0){
        dt_toggle = 1;
        } else if (dt_toggle =! 0){
        dt_toggle = 0;
        dt_toggle_last = 1;
        }
      }
      int1Status = 0;
  }

  // INT2 WAKEUP
  
//  if(digitalRead(int2Pin) == LOW) {
//    //Serial.println("SLEEP");
//    
//    while(true){
//      EVERY_N_MILLISECONDS(25) {                                  // FastLED based non-blocking delay to update/display the sequence.
//        plasma();
//        }
//      EVERY_N_MILLISECONDS(500) {
//        uint8_t maxChanges = 56; 
//        nblendPaletteTowardPalette(currentPalette, targetPalette, maxChanges);   // AWESOME palette blending capability.
//        }
//      EVERY_N_SECONDS(50) {                                 // Change the target palette to a random one every 5 seconds.
//        uint8_t baseC = random8();                         // You can use this as a baseline colour if you want similar hues in the next line.
//        targetPalette = CRGBPalette16(CHSV(baseC+random8(32), 192, random8(128,255)), CHSV(baseC+random8(32), 255, random8(128,255)), CHSV(baseC+random8(32), 192, random8(128,255)), CHSV(baseC+random8(32), 255, random8(128,255)));
//        }
//      FastLED.show();
//    if (digitalRead(int2Pin) == HIGH){
//      break;
//      }
//    }
//    int2Status = 0;
//  }
 
  // Button UP 
  int up_reading = digitalRead(BUTTON_UP);
  if (up_reading == LOW && up_lastReading == HIGH) {
    up_onTime = millis();
  }
  if (up_reading == LOW && up_lastReading == LOW) {
    if ((millis() - up_onTime) > holdTime) {
      // do something when held
      LIGHTSTATE_UP();                                 
      up_hold = 1;
    }
  }
  if (up_reading == HIGH && up_lastReading == LOW ) {
    if (((millis() - up_onTime) > bounceTime) && up_hold != 1) {
      onUPRelease();
    }
    if (up_hold == 1) {
      // do something if released after hold
      up_hold = 0;
    }
  }
  up_lastReading = up_reading;
  if (up_single == 1 && (millis() - up_lastSwitchTime) > doubleTime) {
     // button single click
     LIGHTSTATE_UP();                                    
    up_single = 0;
  }

  // Button DOWN 
  int down_reading = digitalRead(BUTTON_DOWN);
  if (down_reading == LOW && down_lastReading == HIGH) {
    down_onTime = millis();
  }
  if (down_reading == LOW && down_lastReading == LOW) {
    if ((millis() - down_onTime) > holdTime) {
      // do something on hold
      LIGHTSTATE_DOWN();                                     
      down_hold = 1;
    }
  }
  if (down_reading == HIGH && down_lastReading == LOW) {
    if (((millis() - down_onTime) > bounceTime) && down_hold != 1) {
      onDOWNRelease();
    }
    if (down_hold == 1) {
      // do something if released after hold
      down_hold = 0;
    }
  }
  down_lastReading = down_reading;
  if (down_single == 1 && (millis() - down_lastSwitchTime) > doubleTime) {
    // button single click
    LIGHTSTATE_DOWN();
    down_single = 0;
  }
} // loop end

void SLEEP(){
  wu_toggle = 0;
  // Power saving
  //    PRR =  _BV(PRUSART0) | _BV(PRTWI) | _BV(PRSPI); //_BV(PRTIM2) | _BV(PRTIM0) |
  //    MCUCR = _BV(BODSE) | _BV(BODS);
  while(true){
    
      EVERY_N_MILLISECONDS(25) {                                  // FastLED based non-blocking delay to update/display the sequence.
      plasma();
      }
    EVERY_N_MILLISECONDS(500) {
      uint8_t maxChanges = 56; 
      nblendPaletteTowardPalette(currentPalette, targetPalette, maxChanges);   // AWESOME palette blending capability.
      }
    EVERY_N_SECONDS(50) {                                 // Change the target palette to a random one every 5 seconds.
      uint8_t baseC = random8();                         // You can use this as a baseline colour if you want similar hues in the next line.
      targetPalette = CRGBPalette16(CHSV(baseC+random8(32), 192, random8(128,255)), CHSV(baseC+random8(32), 255, random8(128,255)), CHSV(baseC+random8(32), 192, random8(128,255)), CHSV(baseC+random8(32), 255, random8(128,255)));
      }
    FastLED.show();
    
    int kitkat = digitalRead(BUTTON_UP);
      if (kitkat == LOW) {
        break;
      }
  }
      
}




// NTC Sensor dependent LIGHTLEVEL calculation bla
void CHECKTEMP(){ 
  // check for crtitcal temps first !
  // BEAM
  if (avgNTC0() > BEAMCRITTEMP){
    BEAMSTATE = 0;
    analogWrite(BEAM, BEAMSTATE);
    }
  // LIGHT
  if (avgNTC1() > LIGHTCRITTEMP){
    LIGHTSTATE = 0;
    analogWrite(LIGHT, LIGHTSTATE);
    }

  // always down
  if (avgNTC0() > BEAMMAXTEMP && BEAMSTATE > 2){
    BEAMSTATE = BEAMSTATE - 2;
    analogWrite(BEAM, BEAMSTATE);
  }
  if (avgNTC1() > LIGHTMAXTEMP && LIGHTSTATE > 2){
    LIGHTSTATE = LIGHTSTATE - 2;
    analogWrite(LIGHT, LIGHTSTATE);
  }

  // CLEAR ?
  if (dt_toggle_last == 1 && dt_toggle == 0){
      BEAMSTATE = 0;
      analogWrite(BEAM, BEAMSTATE);
      LIGHTSTATE = 0;
      analogWrite(LIGHT, LIGHTSTATE);
      dt_toggle_last = 0;
  }

  // AUTO ?
  if (dt_toggle == 1){
    // LIGHTS UP
    if (avgNTC1() < LIGHTMAXTEMP && LIGHTSTATE < LIGHTPWMLIMIT) {
        LIGHTSTATE = LIGHTSTATE + 1;
        analogWrite(LIGHT, LIGHTSTATE);
      }
    
    // BEAM ON ?
    if (t_toggle == 1){
      if (t_toggle_last == 1){
        if (avgNTC0() < BEAMMAXTEMP && BEAMSTATE < BEAMPWMLIMIT) {
          BEAMSTATE = BEAMPWMLIMIT;
          analogWrite(BEAM, BEAMSTATE);
          t_toggle_last = 0;
        }
      }

      if (avgNTC0() < BEAMMAXTEMP && BEAMSTATE < BEAMPWMLIMIT) {
          BEAMSTATE = BEAMSTATE + 1;
          analogWrite(BEAM, BEAMSTATE);
        }
      if (LIGHTSTATE > 1){
          LIGHTSTATE = 0;
          analogWrite(LIGHT, LIGHTSTATE);
      } 
      
    }
    // BEAM OFF ?
    if (t_toggle == 0){
      if (t_toggle_last == 0){
        if (avgNTC1() < LIGHTMAXTEMP && LIGHTSTATE < LIGHTPWMLIMIT) {
          LIGHTSTATE = LIGHTPWMLIMIT;
          analogWrite(LIGHT, LIGHTSTATE);
          t_toggle_last = 1;
        }
      }

      if (avgNTC1() < LIGHTMAXTEMP && LIGHTSTATE < LIGHTPWMLIMIT) {
          LIGHTSTATE = LIGHTSTATE + 1;
          analogWrite(LIGHT, LIGHTSTATE);
        }
      if (BEAMSTATE > 1){
        BEAMSTATE = 0;
        analogWrite(BEAM, BEAMSTATE);
      }
      
    }
  }
  
  // write lightstate
  APA_bri(BEAMSTATE);
}

//onDOWNRelease button function
void onDOWNRelease() {
  if ((millis() - down_lastSwitchTime) >= doubleTime) {
    down_single = 1;
    down_lastSwitchTime = millis();
    return;
  }
  if ((millis() - down_lastSwitchTime) < doubleTime) {
    READBOOK();                             // do something on double click
    down_single = 0;
    down_lastSwitchTime = millis();
  }
}

//onUPRelease button function
void onUPRelease() {
  if ((millis() - up_lastSwitchTime) >= doubleTime) {
    up_single = 1;
    up_lastSwitchTime = millis();
    return;
  }
  if ((millis() - up_lastSwitchTime) < doubleTime) {
    FLASH();                  // do something on double click
    up_single = 0;
    up_lastSwitchTime = millis();
  }
}

// Brightness routines //
void LIGHTSTATE_UP() {

  if (avgNTC0() > BEAMMAXTEMP | avgNTC1() > LIGHTMAXTEMP ){
    LIGHTSTATE = 10;
    BEAMSTATE = 0;
    analogWrite(LIGHT, LIGHTSTATE);
    analogWrite(BEAM, BEAMSTATE);
    for (int o = 1; o < 20; o++){
      APA_bri(110);
      delay(300);
      APA_bri(255);
      delay(100);
  
    }
  } else {
    while(true){
    if (LIGHTSTATE >= LIGHTPWMLIMIT-5) {
      LIGHTSTATE = LIGHTPWMLIMIT;
      analogWrite(LIGHT, LIGHTSTATE);
      APA_bri(LIGHTSTATE);
      delay(30);
    } else {
      LIGHTSTATE = LIGHTSTATE + 5;
      analogWrite(LIGHT, LIGHTSTATE);
      APA_bri(LIGHTSTATE);
      delay(30);
    }
    int kitkat = digitalRead(BUTTON_UP);
      if (kitkat == HIGH) {
        break;
      }
    }
  }
}

void LIGHTSTATE_DOWN() {
  while(true){
  if (LIGHTSTATE <= 5) {
    LIGHTSTATE = 0;
    analogWrite(LIGHT, LIGHTSTATE);
    APA_bri(LIGHTSTATE);
    delay(30);
  } else {
    LIGHTSTATE = LIGHTSTATE - 5;
    analogWrite(LIGHT, LIGHTSTATE);
    APA_bri(LIGHTSTATE);
    delay(30);
  }
  int kitkat = digitalRead(BUTTON_DOWN);
    if (kitkat == HIGH) {
      break;
    }
  }
}



// BATTERY CALCULATIONS AND SETTINGS
void BATDISP(){

  uint16_t bv = batVCC();                           // read Voltage 
//    Serial.print("bv = ");
//    Serial.println(bv);
  uint16_t dv = bat_full - bat_empty;               // charge range
  uint16_t uv = bv - bat_empty;                     // volts "left"
  float batpercent = (float) uv / dv * 100;         // percent of full charge 
  uint8_t temp = ((int)batpercent * 255)/100;       // make it a value between 0 and 255

  if (bv >= bat_full - 200){
    leds[batled].b = 100;
    leds[batled].g = 230;
    leds[batled].r = 0;
    FastLED.show();
  } else {
    leds[batled].b = 0;
    leds[batled].g = temp;                          // feed it to the display
    leds[batled].r = 255 - temp ;
    FastLED.show();
  }
}

// Nice plasma on the pixels please !
void plasma() {                                                 // This is the heart of this program. Sure is short. . . and fast.
  int thisPhase = beatsin8(6,-64,64);                           // Setting phase change for a couple of waves.
  int thatPhase = beatsin8(7,-64,64);
  for (int k=0; k<NUM_LEDS; k++) {                              // For each of the LED's in the strand, set a brightness based on a wave as follows:
    int colorIndex = cubicwave8((k*23)+thisPhase)/2 + cos8((k*15)+thatPhase)/2;           // Create a wave and add a phase change and add another wave with its own phase change.. Hey, you can even change the frequencies if you wish.
    int thisBright = qsuba(colorIndex, beatsin8(7,0,96));                                 // qsub gives it a bit of 'black' dead space by setting sets a minimum value. If colorIndex < current value of beatsin8(), then bright = 0. Otherwise, bright = colorIndex..
    leds[k] = ColorFromPalette(currentPalette, colorIndex, thisBright, currentBlending);  // Let's now add the foreground colour.
  }
} // plasma()


// Enough to read and last as long as possible
void READBOOK() {
    LIGHTSTATE = 1;                                     // 1 might be too low 
    BEAMSTATE = 0;                                      // no beam
    analogWrite(LIGHT, LIGHTSTATE);
    analogWrite(BEAM, BEAMSTATE);
    leds[briled].b = 0;                                   //these are all off to save energy
    leds[briled].g = 0;                                   // could put plasma here
    leds[briled].r = 0;
    leds[batled].b = 0;
    leds[batled].g = 0;
    leds[batled].r = 0;
    FastLED.show();
}

// unused ... maybe when i finally think of fitting caps parallel to the mosfret (probably need differend mosfets then)
void FLASH(){
  analogWrite(BEAM, BEAMPWMLIMIT);
  delay(100);
  analogWrite(BEAM, BEAMSTATE);
}

//  check supply voltage
long readVcc() {
  ADMUX = 0b01001110;//_BV(REFS0) | _BV(MUX3) | _BV(MUX2) | _BV(MUX1);   // (m328)
  delay(4);                           // Wait for Vref
  ADCSRA |= _BV(ADSC);                // Start conversion
  while (bit_is_set(ADCSRA, ADSC));   // measuring
  uint8_t low  = ADCL;                // must read ADCL first - it then locks ADCH
  uint8_t high = ADCH;                // unlocks both
  long result = (high << 8) | low;
  result = 1140000L / result;         // Calculate Vcc, Bandgap +/- 10 % -- ADJUST !!
  return result;                      // Vcc in millivolts
}

uint16_t batVCC(void) {
    uint16_t imax=0;
    uint16_t imin=65535;
    uint16_t isum=0;
    uint16_t itemp=0;
    uint8_t ctr;
    for (ctr=10;ctr>0;ctr--) {
        itemp=readVcc();
        if (itemp<imin) imin=itemp;
        if (itemp>imax) imax=itemp;
        isum+=itemp;
        delay(4);
    }
    isum-=imin;
    isum-=imax; //subtract the min and max from the sum, now only 8 are left
    itemp=isum/8; //compiler will automatically optimize this to a shift
    return itemp;
}


uint8_t APA_bri(int BRI_setting){

      leds[briled].b = (255 - BRI_setting);
      leds[briled].g = 0;
      leds[briled].r = BRI_setting;
      FastLED.show();
  }

// calculate temp in °C from ntc analog raw data
double Thermistor(int RawADC) {
  double Temp;
  Temp = log(10000.0 * ((1024.0 / RawADC - 1)));
  Temp = 1 / (0.001129148 + (0.000234125 + (0.0000000876741 * Temp * Temp )) * Temp );
  Temp = Temp - 273.15;
  return Temp;
}

uint16_t avgNTC0(void) {
    ADMUX = 0b01000000;
    int val;
    uint16_t imax=0;
    uint16_t imin=65535;
    uint16_t isum=0;
    uint16_t itemp=0;
    uint8_t ctr;
    for (ctr=10;ctr>0;ctr--) {
        val=analogRead(0);
        itemp=Thermistor(val);
        if (itemp<imin) imin=itemp;
        if (itemp>imax) imax=itemp;
        isum+=itemp;
        delay(4);
    }
    isum-=imin;
    isum-=imax; //subtract the min and max from the sum, now only 8 are left
    itemp=isum/8; //compiler will automatically optimize this to a shift
    return itemp;
}

uint16_t avgNTC1(void) {
    ADMUX = 0b01000001;
    int val;
    uint16_t imax=0;
    uint16_t imin=65535;
    uint16_t isum=0;
    uint16_t itemp=0;
    uint8_t ctr;
    for (ctr=10;ctr>0;ctr--) {
        val=analogRead(1);
        itemp=Thermistor(val);
        if (itemp<imin) imin=itemp;
        if (itemp>imax) imax=itemp;
        isum+=itemp;
        delay(4);
    }
    isum-=imin;
    isum-=imax; //subtract the min and max from the sum, now only 8 are left
    itemp=isum/8; //compiler will automatically optimize this to a shift
    return itemp;
}
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

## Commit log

2017-09-15 eside revision 8 and neopixel matrix
    flatlight made for marvin with an atmega16a-au.
    layout for neopixel and cree xp something power led on ledside.
    dedicated battery check and temperature control.
    [_saved_modular_SMALL_rgb_neopixel_matrix.sch, modular_SMALL_rgb_neopixel_matrix.kicad_pcb, modular_SMALL_rgb_neopixel_matrix.sch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]
2017-11-06 new file: KiCAD/FOOTPRINTS/ESP32-footprints-Lib.pretty/ESP32-WROOM.kicad_mod new file: KiCAD/FOOTPRINTS/ESP32-footprints-Lib.pretty/ESP32.kicad_mod new file: KiCAD/FOOTPRINTS/ESP32-footprints-Lib.pre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
2017-11-12 Added LED Matrix controls
2018-09-01 changed tree and added Rev15
    [_saved_modular_SMALL_rgb_neopixel_matrix.sch, eside_rev15.kicad_pcb, eside_rev15.sch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]
2018-09-01 Some deletions
    [_saved_modular_SMALL_rgb_neopixel_matrix.sch, modular_SMALL_rgb_neopixel_matrix.kicad_pcb, modular_SMALL_rgb_neopixel_matrix.sch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]
2019-07-13 Add files via upload
    rev17
    [eside_rev17.kicad_pcb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]
2019-07-13 Add files via upload
    integrated IMU
2019-07-15 Added Blender history
    [flatlight_rev17_1.blend, flatlight_rev17_10.blend, flatlight_rev17_10.stl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]
2019-07-15 Updated Structure
    [eside_rev17.kicad_pcb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]
2019-07-16 updated blender and arduino
    [flatlight_rev17_22.blend, flatlight_rev17_22.stl, flatlight_rev17_23-Cube_001.stl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]
2019-12-23 flatlight revision 18 A
    [eside_rev18.kicad_pcb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]
2019-12-23 updated blender files
    added frame modifications for headband use in REV 17
    [flatlight_rev17_27.blend, flatlight_rev17_28.blend, flatlight_rev17_28.stl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]
2020-01-16 updated REV18
    [eside_rev18.csv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]
2020-01-16 updated kiCAD
    [eside_rev18.kicad_pcb, eside_rev18.sch, ledside_rev18A.kicad_pcb]

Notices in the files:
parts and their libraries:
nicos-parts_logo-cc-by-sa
